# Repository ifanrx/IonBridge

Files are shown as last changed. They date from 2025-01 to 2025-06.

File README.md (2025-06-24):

# IonBridge

This repository contains the open-source power management module for the power adapter developed by ifanr / CANDYSIGN.

## 许可

请参阅 LICENSE 文件以了解更多详细信息。

我们欢迎非商业用途和小批量（单一型号总生产量小于等于一百台）使用。然而，对于大批量或盈利生产，需要获得商业许可。

请注意，虽然这是一个开源软件项目，但这并不意味着我们放弃了对该项目的版权。

## License
Please refer to the LICENSE file for more details.

We welcome non-commercial use and small batch runs. However, for larger batch or for-profit productions, a commercial license is required.

Please note that although this is an open-source software project, it does not mean we are relinquishing copyright to it.

## Contributing
The project is still in its early stages. We are currently sorting out copyright issues with our legal team to ensure we can legally acquire a perpetual, non-exclusive license for contributions while remaining in compliance with the relevant legal framework. 

As a result, we are unable to accept external contributions at this time. Stay tuned for updates! Once the issues are resolved, you will be required to sign a Contributor License Agreement (CLA) to authorize us to use your copyrighted work non-exclusively.

##  What's Missing
The proprietary implementation of power allocation is a patented feature and is not included in the open-source scope of this repository.

## Development Setup
To get started, you need to install the [ESP-IDF](https://docs.espressif.com/projects/esp-idf/en/latest/esp32/get-started/)

### Prerequisites
Install the required dependencies:

```bash
$ brew install cmake ninja dfu-util
# Install Python 3 if it's not already installed
$ brew install python3
```

### Getting ESP-IDF
Clone the ESP-IDF repository and set it up:

```bash
$ mkdir -p ~/esp
$ cd ~/esp
$ git clone --recursive https://github.com/espressif/esp-idf.git
$ cd esp-idf
$ git checkout v5.4
```

### Updating Submodules
Update the ESP-IDF submodules:

```bash
$ cd ~/esp/esp-idf
$ git submodule update --init --recursive
```

### Installing ESP-IDF Tools
Run the installation script to install the ESP-IDF tools:

```bash
$ ./install.sh all
```

### Setting Environment Variables
Set up the required environment variables:

```bash
$ . $HOME/esp/esp-idf/export.sh
```
Alternatively, you can add the following alias to your shell profile for convenience:

```bash
alias get_idf='. $HOME/esp/esp-idf/export.sh'
```

### Configure the ESP32 Target
Navigate to the project root directory and set the ESP32 target:

```bash
$ idf.py set-target esp32c3
```

Copy sdkconfig.develop or sdkconfig.fake to sdkconfig:

```bash
$ cp configs/sdkconfig.develop sdkconfig
```

### Build the Project
Build the project using the following command:

```bash
$ idf.py build
```

## HummingBoard
HummingBoard is a fully functional development board for the power adapter in this project, designed specifically for development and testing.

- **Comprehensive Features**: Provides a complete development environment for power conversion.
- **Schematic Support**: You can find detailed schematics and related documentation in [HummingBoard](/HummingBoard/).

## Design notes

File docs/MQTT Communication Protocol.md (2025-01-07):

# MQTT Communication Protocol

## Table of Contents

- [MQTT Communication Protocol](#mqtt-communication-protocol)
  - [Table of Contents](#table-of-contents)
  - [Overview](#overview)
  - [Design Architecture](#design-architecture)
    - [Device Information](#device-information)
    - [Message Structure](#message-structure)
      - [Status Byte](#status-byte)
      - [Example Response](#example-response)
    - [Command Handling](#command-handling)
  - [Core Components](#core-components)
    - [MQTT Message Schema](#mqtt-message-schema)
      - [Header](#header)
      - [Base Message Class](#base-message-class)
    - [Telemetry Commands](#telemetry-commands)
    - [Message Serialization](#message-serialization)
    - [Usage](#usage)
    - [Examples](#examples)
      - [Sending Device Boot Info](#sending-device-boot-info)
      - [Parsing Incoming Messages](#parsing-incoming-messages)

---

## Overview

We have developed an MQTT-based protocol that facilitates efficient and reliable communication between devices and cloud services. Key features of the protocol include:

- **Device Identification**: Utilizes a unique "PSN" (Product Serial Number) to accurately identify device-specific messages.
- **Optimized Message Serialization**: Implements binary serialization to significantly enhance communication efficiency and reduce payload size.
- **Flexible Structured Design**: Features a structured format for message headers and payloads, enabling seamless support for diverse telemetry data and control commands.

For a practical implementation, refer to [`mqtt_client.py`](../python/mqtt_client.py). This file contains the complete implementation of the mqtt communication protocol, and you can start your development by editing this Python file.

---

## Design Architecture

### Device Information

Each device is identified using a `PSN` (Product Serial Number), stored in the ESP32's `protected_data` partition under the key `serial_number`. This ensures unique identification for each device during communication.

---

### Message Structure

- **Header**: Includes service ID and payload length for efficient parsing.
- **Payload**: Varies based on command and data type.

#### Status Byte

- `0x00`: Success
- `0x01`: Failure
- Other bytes represent specific API-defined data.

#### Example Response

For the command `GET_POWER_SUPPLY_STATUS`:
- `0x00`: Indicates success.
- `0x1F`: Binary `11111` means 5 ports are active.

---

### Command Handling

The system supports unified handlers for both BLE and MQTT commands. This ensures consistent behavior across communication protocols.

---

## Core Components

### MQTT Message Schema

Header and payload structures are implemented in `mqtt_message.h` to define and serialize MQTT messages.

#### Header

```cpp
struct MQTTMessageHeader {
  uint16_t service;
  uint16_t message_id;
};
```

#### Base Message Class

```cpp
struct MQTTMessage {
  MQTTMessageHeader header;
  virtual ~MQTTMessage() = default;
  virtual std::vector<uint8_t> serialize() const;
};
```

### Telemetry Commands
Defined commands handle various telemetry and control tasks:

```cpp
enum TelemetryServiceCommand : uint16_t {
  STREAM_PORTS_STATUS = 0x0080,
  STREAM_DEVICE_STATUS = 0x0081,
  PING = 0x0100,
  DEVICE_BOOT_INFO = 0x0110,
  POWER_HISTORICAL_DATA = 0x0130,
  // Additional commands...
};
```

### Message Serialization
All message structures provide a serialize() method to convert their fields into a byte array for transmission.

Example: `StreamPortStatus`

```cpp
struct StreamPortStatus : MQTTMessage {
  uint8_t status;
  uint8_t port_status_map;
  PortStatusData ports[8];

  std::vector<uint8_t> serialize() const override {
    std::vector<uint8_t> payload = header.serialize();
    payload.emplace_back(status);
    payload.emplace_back(port_status_map);
    // Serialize each port's data
    for (const auto &port : ports) {
      const uint8_t *portData = reinterpret_cast<const uint8_t *>(&port);
      payload.insert(payload.end(), portData, portData + sizeof(PortStatusData));
    }
    return payload;
  }
};
```

### Usage
To integrate this framework into your project:

1. Include the mqtt_message.h header file in your project.
2. Define your specific telemetry or control commands.
3. Use the serialize() methods to prepare payloads for MQTT transmission.

### Examples
#### Sending Device Boot Info

```cpp
DeviceBootInfo bootInfo = { /* Initialize fields */ };
std::vector<uint8_t> payload = bootInfo.serialize();
// Send payload over MQTT
```

#### Parsing Incoming Messages

```cpp
void handleIncomingMessage(const std::vector<uint8_t>& payload) {
  // Deserialize based on header service ID
}
```

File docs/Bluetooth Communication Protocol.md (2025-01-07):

# Bluetooth Communication Protocol

## Table of Contents
- [Bluetooth Communication Protocol](#bluetooth-communication-protocol)
  - [Table of Contents](#table-of-contents)
  - [Overview](#overview)
  - [Protocol Design](#protocol-design)
    - [Message Structure](#message-structure)
    - [Flags](#flags)
  - [Key Functionalities](#key-functionalities)
    - [Message Size Encoding](#message-size-encoding)
    - [Checksum Validation](#checksum-validation)
  - [Communication Workflow](#communication-workflow)
  - [Example Workflow](#example-workflow)
    - [Device Status Request](#device-status-request)
  - [Code Snippets](#code-snippets)
    - [Message Processing](#message-processing)
    - [Exponential Backoff for Retransmissions](#exponential-backoff-for-retransmissions)

---

## Overview

We have designed a robust BLE communication protocol to enable fast, reliable, and secure interaction with devices. The protocol includes the following key features:

- **Data Encapsulation**: Ensures information integrity through modular and structured data transmission.
- **Optimized for Small MTU**: Tailored for efficient communication in environments with limited MTU sizes.
- **Sequence Control**: Ensures ordered and reliable data transmission using serialization mechanisms.
- **Built-in Information Verification**: Enhances communication security and reliability with integrated verification processes.

For a practical implementation, refer to [`ble_tester.py`](../python/ble_tester.py). This file contains the complete implementation of the Bluetooth communication protocol, and you can start your development by editing this Python file.

---

## Protocol Design

### Message Structure

Each message consists of a header and a payload:

```c
typedef struct { // 9 bytes
  uint8_t version;     // Protocol version 0x1 
  uint8_t id;          // Unique ID for each message
  int8_t service;      // Service ID (positive: send, negative: receive)
  uint8_t sequence;    // Sequence number for fragmentation
  uint8_t flags;       // Transmission control flags 
  ble_size_t size;     // Total size of the message payload
  uint8_t checksum;    // Checksum for integrity validation
} BLEHeader;

typedef struct {
  BLEHeader header;
  uint8_t payload[];    // Flexible array for payload data
} Message;
```

### Flags
The flags byte contains information for fragmentation and transmission control:

- Flags (Bits 0–2):

  * 0x0: NONE
  * 0x1: SYN (connection request)
  * 0x2: ACK (acknowledgment)
  * 0x3: FIN (termination request)
  * 0x4: RST (reset connection)
  * 0x5: SYN+ACK (connection acknowledgment)

- Fragmentation Flags (Bits 3–4):

  * 0x0: No fragment
  * 0x1: First fragment
  * 0x2: More fragments
  * 0x3: Last fragment

## Key Functionalities
### Message Size Encoding
ble_size_t is a 3-byte structure used to encode and decode the payload size efficiently:

```c
typedef struct {
    uint8_t bytes[3];
} ble_size_t;

// Convert `ble_size_t` to `uint32_t`
uint32_t get_ble_size_t(ble_size_t b) {
    uint32_t result = 0;
    result |= ((uint32_t)b.bytes[0]) << 16;
    result |= ((uint32_t)b.bytes[1]) << 8;
    result |= ((uint32_t)b.bytes[2]);
    return result;
}

// Convert `uint32_t` to `ble_size_t`
ble_size_t set_ble_size_t(uint32_t value) {
    ble_size_t b;
    b.bytes[0] = (value >> 16) & 0xFF;
    b.bytes[1] = (value >> 8) & 0xFF;
    b.bytes[2] = value & 0xFF;
    return b;
}
```
### Checksum Validation
The checksum field ensures message integrity:

```cpp
uint8_t calcChecksum(BLEHeader *header) {
    const uint8_t *begin = reinterpret_cast<const uint8_t *>(header);
    const uint8_t *end = begin + sizeof(BLEHeader) - 1; // Exclude checksum byte
    return std::accumulate(begin, end, static_cast<uint8_t>(0));
}

bool validateChecksum(BLEHeader *header) {
    uint8_t expected_checksum = header->checksum;
    header->checksum = 0;
    uint8_t calculated_checksum = calcChecksum(header);
    header->checksum = expected_checksum;
    return calculated_checksum == expected_checksum;
}
```

## Communication Workflow

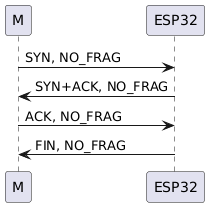
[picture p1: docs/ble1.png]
ble-1


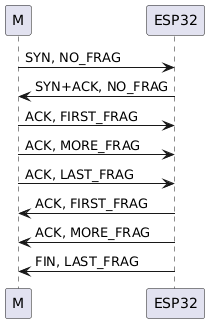
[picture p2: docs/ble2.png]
ble-2


1. Handshake (Connection Establishment)
Sender:
Sends a SYN packet with the requested service ID and optional payload.
Receiver:
Processes the payload and responds with a SYN+ACK packet.
This process reduces the usual three-way handshake to two steps for efficiency.

2. Data Exchange
For large data, use fragmentation (FRAG FLAGS):
First fragment: 0x1
More fragments: 0x2
Last fragment: 0x3
Receiver acknowledges (ACK) each received packet.
3. Connection Termination
Sender:
Sends a FIN packet, optionally with a final payload.
Receiver:
Processes the payload and responds with an ACK.
This simplified termination avoids the traditional four-step handshake, making the process faster.

## Example Workflow
### Device Status Request
1. Sender: Sends SYN requesting the device status.
2. Receiver: Responds with SYN+ACK, providing the current status.
3. Sender: Sends additional configuration requests.
4. Receiver: Responds with a FIN packet after completing the operation.
5. Sender: Acknowledges the FIN with an ACK.

## Code Snippets
### Message Processing
``` cpp
void process_message(Message &msg, IMessageHandler &handler) {
    ESP_LOGD(TAG, "Processing message with ID: %d", msg.getID());
    uint8_t flags = msg.getFlags() & 0x7;
    uint8_t frag_flags = (msg.getFlags() >> 3) & 0x3;

    switch (flags) {
        case SYN:
            handler.handle_syn(msg);
            break;
        case SYN_ACK:
            handler.handle_syn_ack(msg);
            break;
        case ACK:
            handler.handle_ack(msg);
            break;
        case FIN:
            handler.handle_fin(msg);
            break;
    }
}
```
### Exponential Backoff for Retransmissions
```cpp
const int backoff_intervals[] = {128, 256, 512, 1024, 2048, 4096};

void retransmit_message(Message &msg, int retry_count) {
    if (retry_count >= sizeof(backoff_intervals) / sizeof(backoff_intervals[0])) {
        ESP_LOGE(TAG, "Maximum retries reached");
        return;
    }
    int backoff = backoff_intervals[retry_count];
    ESP_LOGI(TAG, "Retransmitting message with backoff: %d ms", backoff);
    vTaskDelay(backoff / portTICK_PERIOD_MS);
    send_message(msg); // Assume send_message() handles actual transmission
}
```

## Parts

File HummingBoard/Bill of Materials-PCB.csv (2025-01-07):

Comment | Designator | Footprint | Quantity
ANT3216LL00R2400A | AE1 | ANT3216LL00R2400A | 1
CL05A106MQ5NUNC | C1_U_SW35660, C1_U_SW35661, C1_U_SW35662, C1_U_SW35663, C1_U_SW35664, C4_U_SW35660, C4_U_SW35661, C4_U_SW35662, C4_U_SW35663, C4_U_SW35664, C16_U_SW35660, C16_U_SW35661, C16_U_SW35662, C16_U_SW35663, C16_U_SW35664, C32, C40, C45, C48 | CAPC1005X06N | 19
CL05B104KB54PNC | C2_U_SW35660, C2_U_SW35661, C2_U_SW35662, C2_U_SW35663, C2_U_SW35664, C7_U_SW35660, C7_U_SW35661, C7_U_SW35662, C7_U_SW35663, C7_U_SW35664, C8_U_SW35660, C8_U_SW35661, C8_U_SW35662, C8_U_SW35663, C8_U_SW35664, C9_U_SW35660, C9_U_SW35661, C9_U_SW35662, C9_U_SW35663, C9_U_SW35664, C15_U_SW35660, C15_U_SW35661, C15_U_SW35662, C15_U_SW35663, C15_U_SW35664, C19, C24, C25, C30, C31, C35, C36, C41, C42, C43, C44, C46, C47, C49, C50, C51, C52, C53, C55, C56, C57, C58 | CAPC1005X06N | 47
GRM21BR61H106KE43L | C3_U_SW35660, C3_U_SW35661, C3_U_SW35662, C3_U_SW35663, C3_U_SW35664, C26 | CAPC2012X14N | 6
FS55X226K500EHG | C5_U_SW35660, C5_U_SW35661, C5_U_SW35662, C5_U_SW35663, C5_U_SW35664, C6_U_SW35660, C6_U_SW35661, C6_U_SW35662, C6_U_SW35663, C6_U_SW35664, C10_U_SW35660, C10_U_SW35661, C10_U_SW35662, C10_U_SW35663, C10_U_SW35664, C11_U_SW35660, C11_U_SW35661, C11_U_SW35662, C11_U_SW35663, C11_U_SW35664, C12_U_SW35660, C12_U_SW35661, C12_U_SW35662, C12_U_SW35663, C12_U_SW35664, C13_U_SW35660, C13_U_SW35661, C13_U_SW35662, C13_U_SW35663, C13_U_SW35664, C14_U_SW35660, C14_U_SW35661, C14_U_SW35662, C14_U_SW35663, C14_U_SW35664, C20, C21, C22, C23 | CAPC5750X31N | 39
0402B222K500NT | C17_U_SW35660, C17_U_SW35661, C17_U_SW35662, C17_U_SW35663, C17_U_SW35664 | CAPC1005X06N | 5
0402CG101J500NT | C18_U_SW35660, C18_U_SW35661, C18_U_SW35662, C18_U_SW35663, C18_U_SW35664 | CAPC1005X06N | 5
CL31A107MQHNNNE | C27 | CAPC3216X18N | 1
CL05B103KB5NNNC | C28, C37 | CAPC1005X06N | 2
0402B472K500NT | C29 | CAPC1005X06N | 1
CC0402BRNPO9BNR47 | C33 | CAPC1005X06N | 1
0402CGR75C500NT | C34 | CAPC1005X06N | 1
CL05A105KA5NQNC | C38, C39 | CAPC1005X06N | 2
CC0402KRX7R9BB332 | C54 | CAPC1005X06N | 1
SRV05-4-P-T7 | D1_U_SW35660, D1_U_SW35661, D1_U_SW35662, D1_U_SW35663, D1_U_SW35664 | SOT-23-6 | 5
P6SMB39A | D2 | SMB DO-214AA | 1
SS54C | D3 | SMC | 1
E6C0805URAC1UDA | D4 | DIOC2012X11N | 1
TYPE-C-31-M-12 | J1_U_SW35660, J1_U_SW35661, J1_U_SW35662, J1_U_SW35663, J1_U_SW35664, J3 | TYPE-C-31-M-12 | 6
XT60PW-M | J2 | XT60PW-M | 1
A1251WV-S-6P | J4 | A1251WV-S-6P | 1
B-3000N10P-0110 | J5 | B-3000N10P-0110 | 1
SER1360-103KLD | L1_U_SW35660, L1_U_SW35661, L1_U_SW35662, L1_U_SW35663, L1_U_SW35664, L2 | SER1360 | 6
MLG1005S1N8BT000 | L3, L5, L6 | INDC1005X06N | 3
VHF100505HQ1N5ST | L4 | INDC1005X06N | 1
RUH4040M2 | Q1_U_SW35660, Q1_U_SW35661, Q1_U_SW35662, Q1_U_SW35663, Q1_U_SW35664, Q2_U_SW35660, Q2_U_SW35661, Q2_U_SW35662, Q2_U_SW35663, Q2_U_SW35664, Q3_U_SW35660, Q3_U_SW35661, Q3_U_SW35662, Q3_U_SW35663, Q3_U_SW35664 | DNH0008A | 15
0402WGF1002TCE | R1_U_SW35660, R1_U_SW35661, R1_U_SW35662, R1_U_SW35663, R1_U_SW35664, R2_U_SW35660, R2_U_SW35661, R2_U_SW35662, R2_U_SW35663, R2_U_SW35664, R3_U_SW35660, R3_U_SW35661, R3_U_SW35662, R3_U_SW35663, R3_U_SW35664, R6_U_SW35660, R6_U_SW35661, R6_U_SW35662, R6_U_SW35663, R6_U_SW35664, R7_U_SW35660, R7_U_SW35661, R7_U_SW35662, R7_U_SW35663, R7_U_SW35664, R23, R24, R25, R27, R28, R29, R30, R31, R32, R34 | RESC1005X04N | 35
NCP15XH103F03RC | R4_U_SW35660, R4_U_SW35661, R4_U_SW35662, R4_U_SW35663, R4_U_SW35664 | RESC1005X04N | 5
RC0402FR-0710KL | R5_U_SW35660, R5_U_SW35661, R5_U_SW35662, R5_U_SW35663, R5_U_SW35664, R17 | RESC1005X04N | 6
RLM12FTCMR003 | R8_U_SW35660, R8_U_SW35661, R8_U_SW35662, R8_U_SW35663, R8_U_SW35664, R10 | RESC3116X06N | 6
0402WGF2002TCE | R9_U_SW35660, R9_U_SW35661, R9_U_SW35662, R9_U_SW35663, R9_U_SW35664, R19 | RESC1005X04N | 6
0603WAF500LT5E | R11, R12, R13, R14 | RESC1608X06N | 4
0402WGF3162TCE | R15 | RESC1005X04N | 1
0402WGF1003TCE | R16, R18 | RESC1005X04N | 2
0402WGF3300TCE | R20 | RESC1005X04N | 1
0402WGF5101TCE | R21, R22 | RESC1005X04N | 2
0402WGF1000TCE | R26 | RESC1005X04N | 1
0402WGF220JTCE | R33 | RESC1005X04N | 1
GT-TC029A-H020-L1A | S1 | GT-TC029A-H020-L1A | 1
MTP125-1101S1 | TP1_U_SW35660, TP1_U_SW35661, TP1_U_SW35662, TP1_U_SW35663, TP1_U_SW35664, TP2_U_SW35660, TP2_U_SW35661, TP2_U_SW35662, TP2_U_SW35663, TP2_U_SW35664, TP3_U_SW35660, TP3_U_SW35661, TP3_U_SW35662, TP3_U_SW35663, TP3_U_SW35664, TP4_U_SW35660, TP4_U_SW35661, TP4_U_SW35662, TP4_U_SW35663, TP4_U_SW35664, TP5_U_SW35660, TP5_U_SW35661, TP5_U_SW35662, TP5_U_SW35663, TP5_U_SW35664, TP6_U_SW35660, TP6_U_SW35661, TP6_U_SW35662, TP6_U_SW35663, TP6_U_SW35664, TP7_U_SW35660, TP7_U_SW35661, TP7_U_SW35662, TP7_U_SW35663, TP7_U_SW35664, TP8_U_SW35660, TP8_U_SW35661, TP8_U_SW35662, TP8_U_SW35663, TP8_U_SW35664, TP9_U_SW35660, TP9_U_SW35661, TP9_U_SW35662, TP9_U_SW35663, TP9_U_SW35664, TP10_U_SW35660, TP10_U_SW35661, TP10_U_SW35662, TP10_U_SW35663, TP10_U_SW35664, TP11_U_SW35660, TP11_U_SW35661, TP11_U_SW35662, TP11_U_SW35663, TP11_U_SW35664, TP12_U_SW35660, TP12_U_SW35661, TP12_U_SW35662, TP12_U_SW35663, TP12_U_SW35664, TP13, TP14, TP15 | MTP125-1101S1 | 63
SW3566H | U1_U_SW35660, U1_U_SW35661, U1_U_SW35662, U1_U_SW35663, U1_U_SW35664 | QFN-32 | 5
TP181A2-CR | U2 | 3PEAK SC70-6 SOT-363 | 1
TPS54240DGQR | U3 | DGQ0010D | 1
ESP32-C3 | U4 | ESPRESSIF-QFN32-5*5 | 1
W25Q64JVSSIQ | U5 | W25QXXXJVSIQ | 1
EF2M45LG48B | U6 | ANLOGIC_LQFP48 | 1
SiT2001BI-S1-33E-40.000000 | Y1 | SITIME_SIT2001_SOT23 | 1

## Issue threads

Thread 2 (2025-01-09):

功能请求：添加 Switch 底座识别功能，固定输出功率为 45W

chouch0u, 2025-01-09:
## 背景说明：
Nintendo Switch 在底座模式下对电源有特定的功率需求。通过自动识别 Switch 底座的连接，可以优化充电器输出，提供稳定的 45W 功率防止别的设备插入导致游戏中断。

## 具体需求：

### 识别机制：

充电器应通过 USB-PD 协议 PID VID 识别 Switch 底座。

### 固定输出功率：

当识别到 Switch 底座后，充电器自动切换到 45W（15V/3A）的固定输出模式。

### 兼容性保障：

在 Switch 底座识别失败或不兼容设备连接的情况下，充电器应回退到默认输出模式，避免不必要的误判。

### 预期收益：

提高充电器的设备适配能力，增加对 Switch 用户的吸引力。提供更稳定的输出功率，防止因功率分配导致的外接显示设备输出中断，提升用户体验。

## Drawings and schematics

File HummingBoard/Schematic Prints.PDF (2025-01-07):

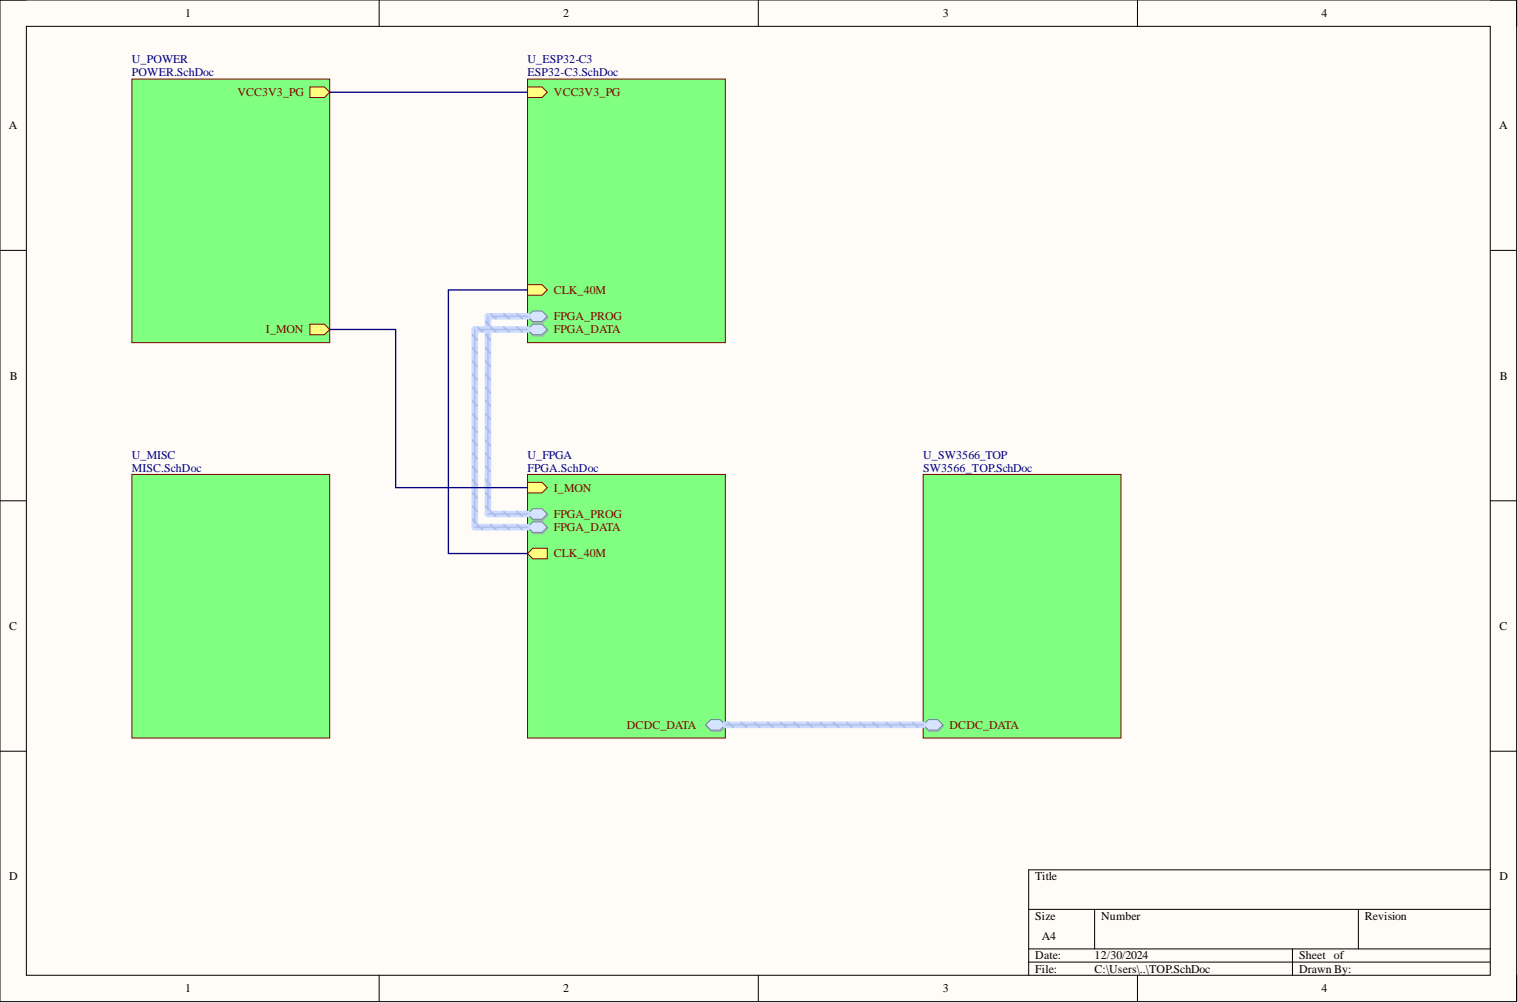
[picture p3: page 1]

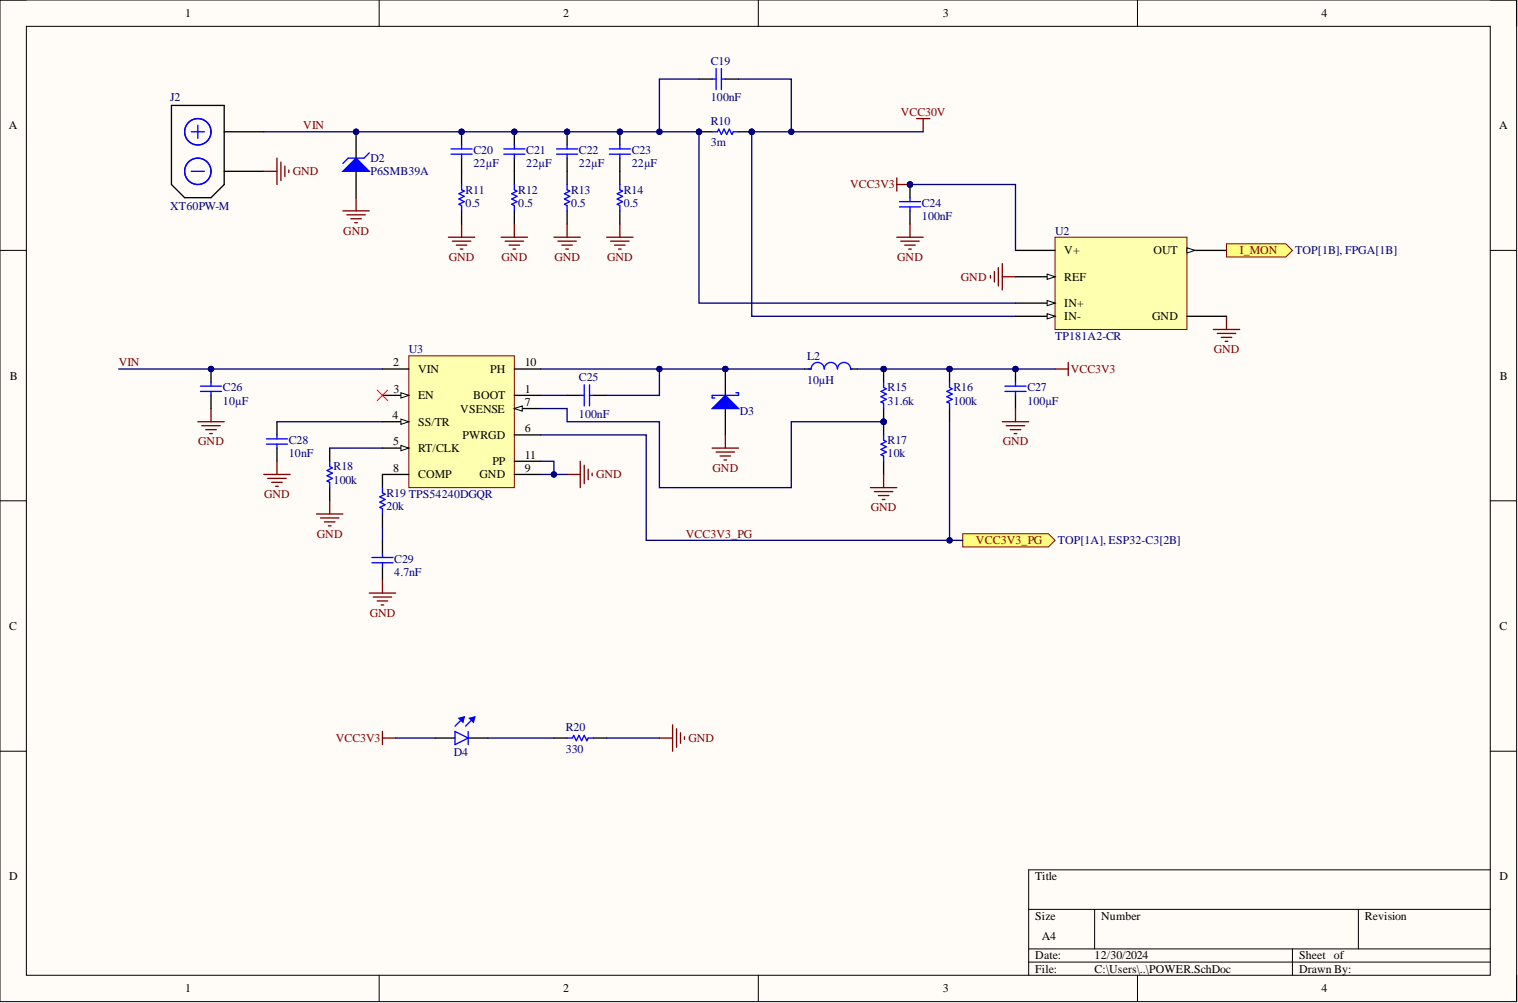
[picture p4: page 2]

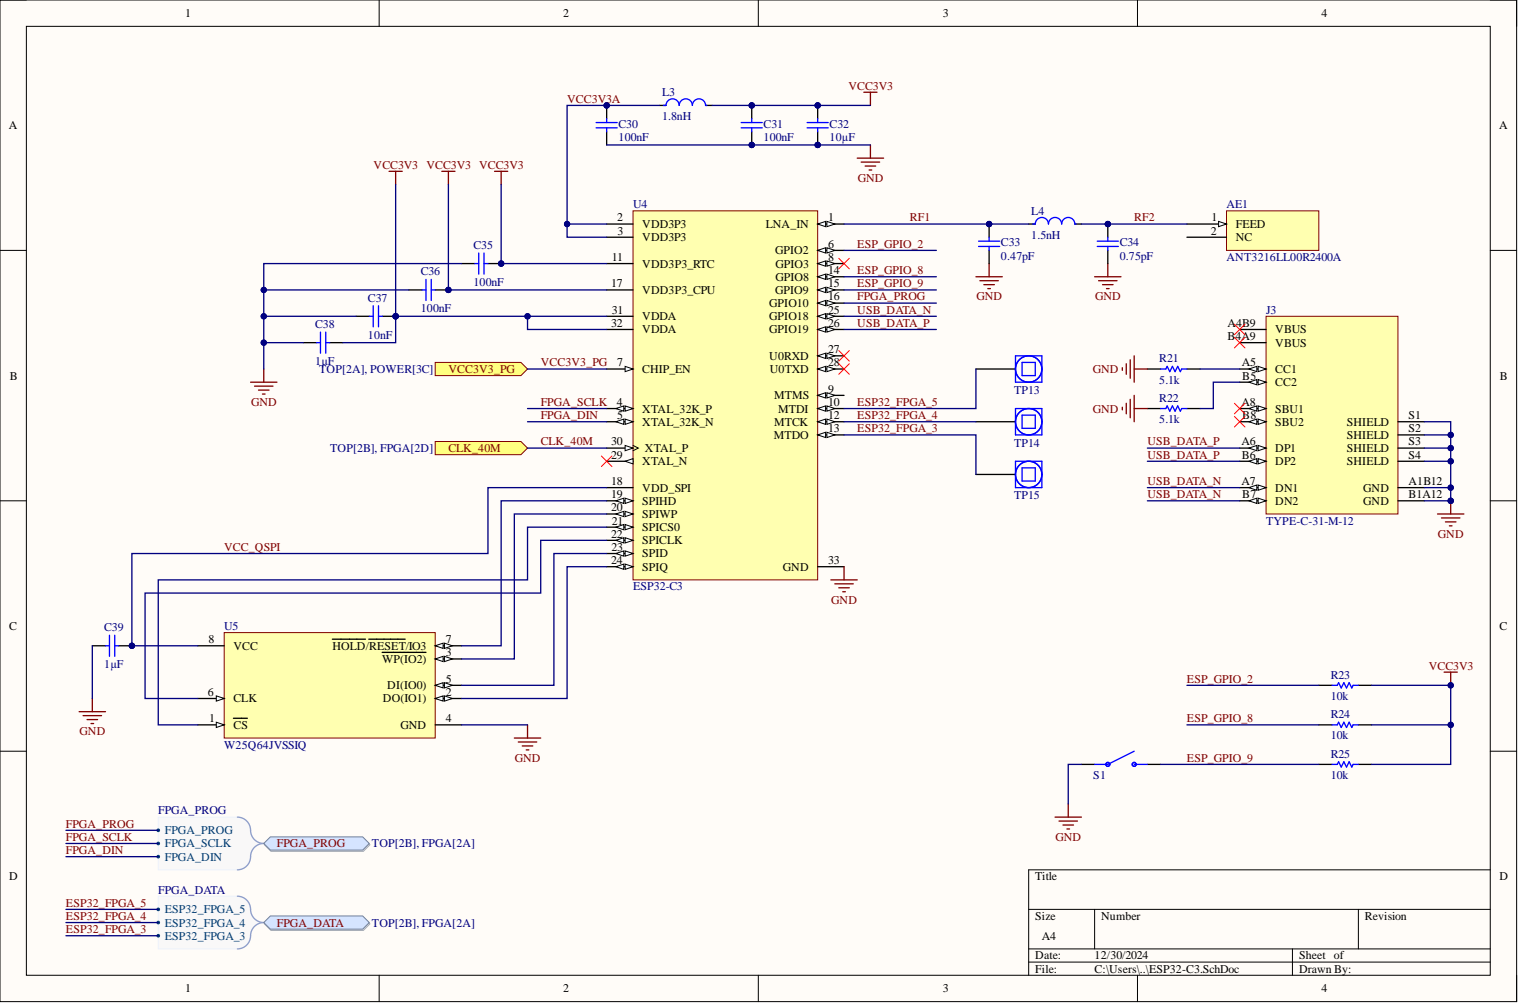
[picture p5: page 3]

SPIWP 20
SPICS0 21
SPICLK 22
SPID 23
SPIQ 24

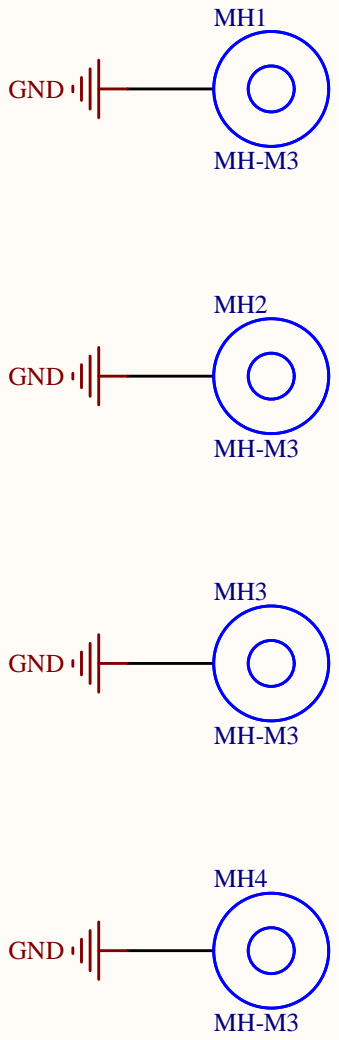
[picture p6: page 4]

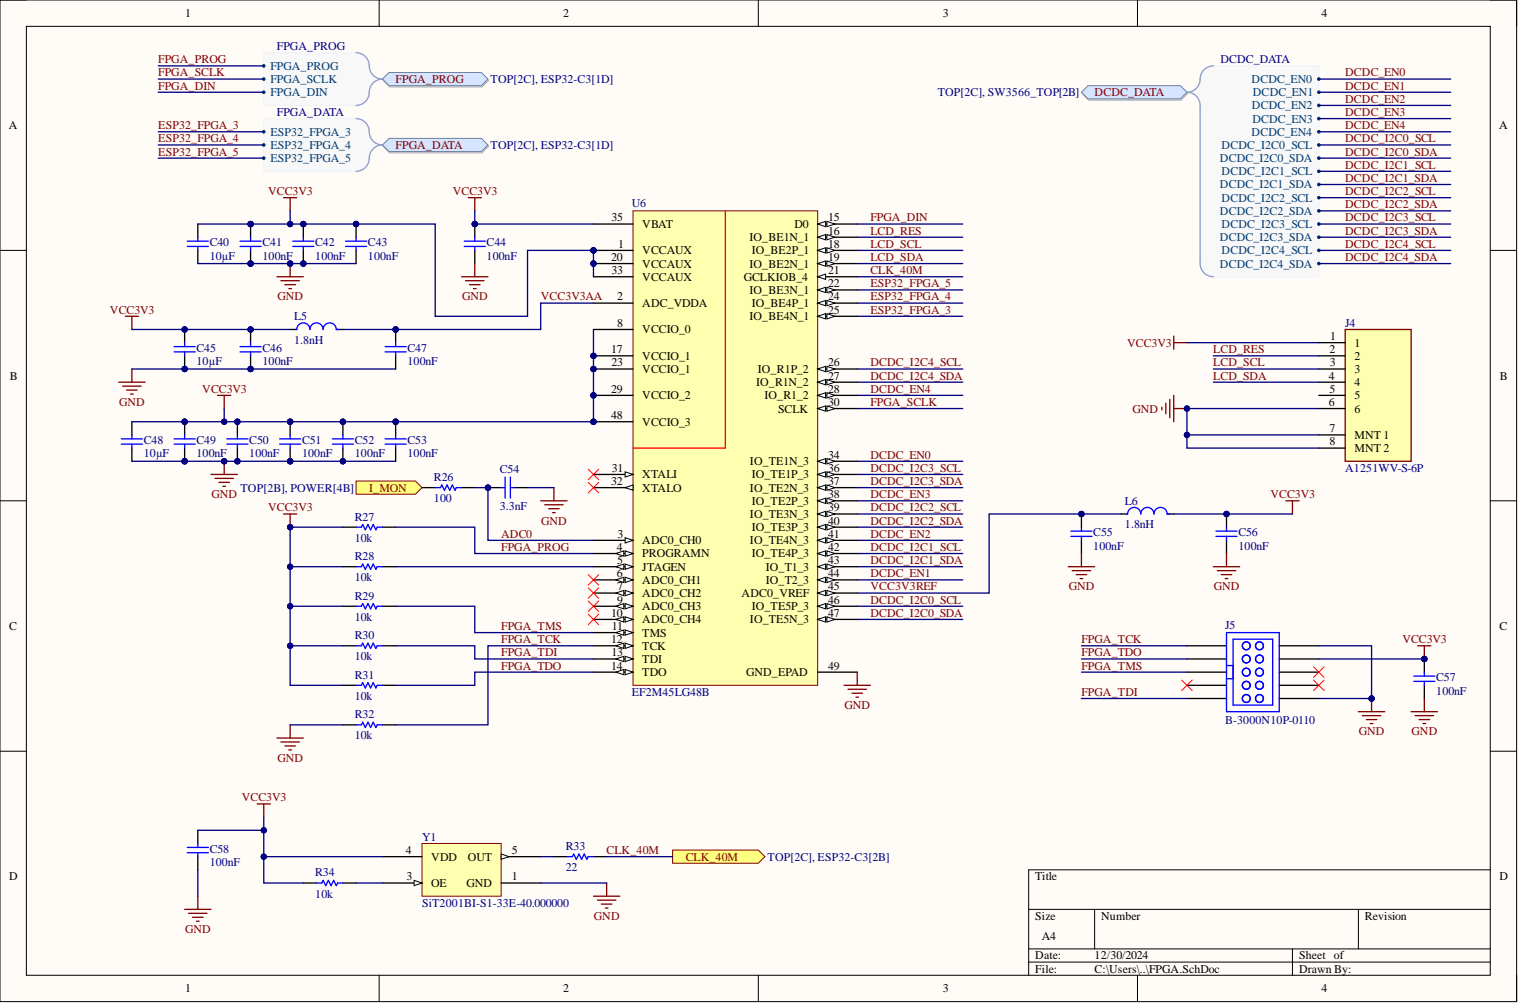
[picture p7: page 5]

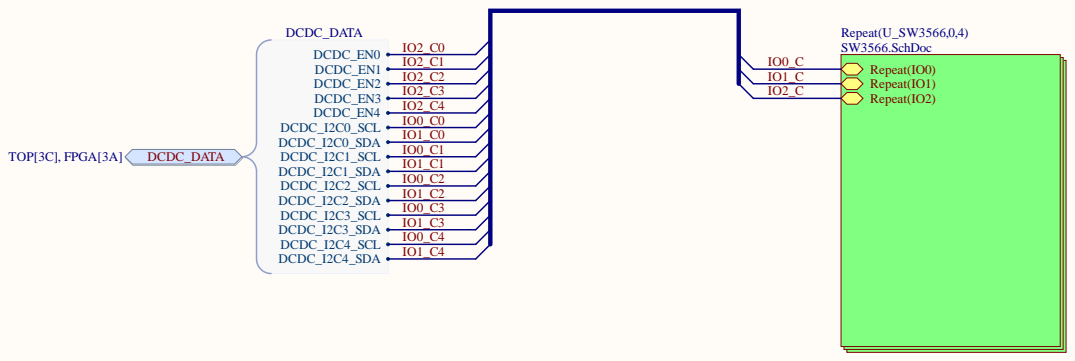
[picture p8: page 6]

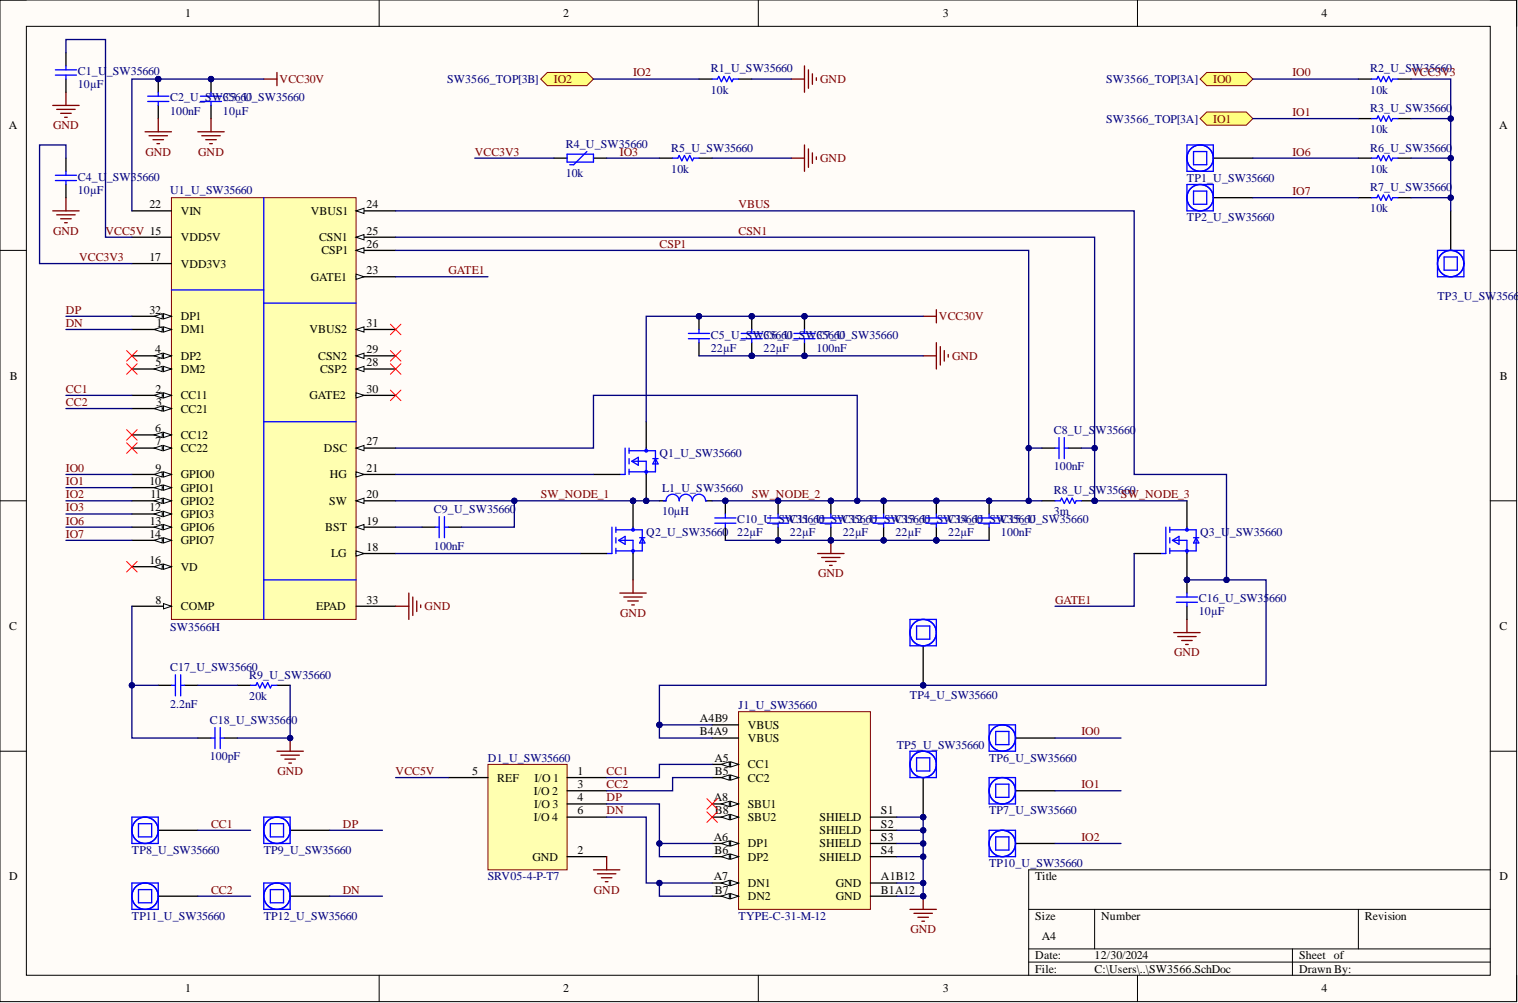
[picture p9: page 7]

VBUS B4A9

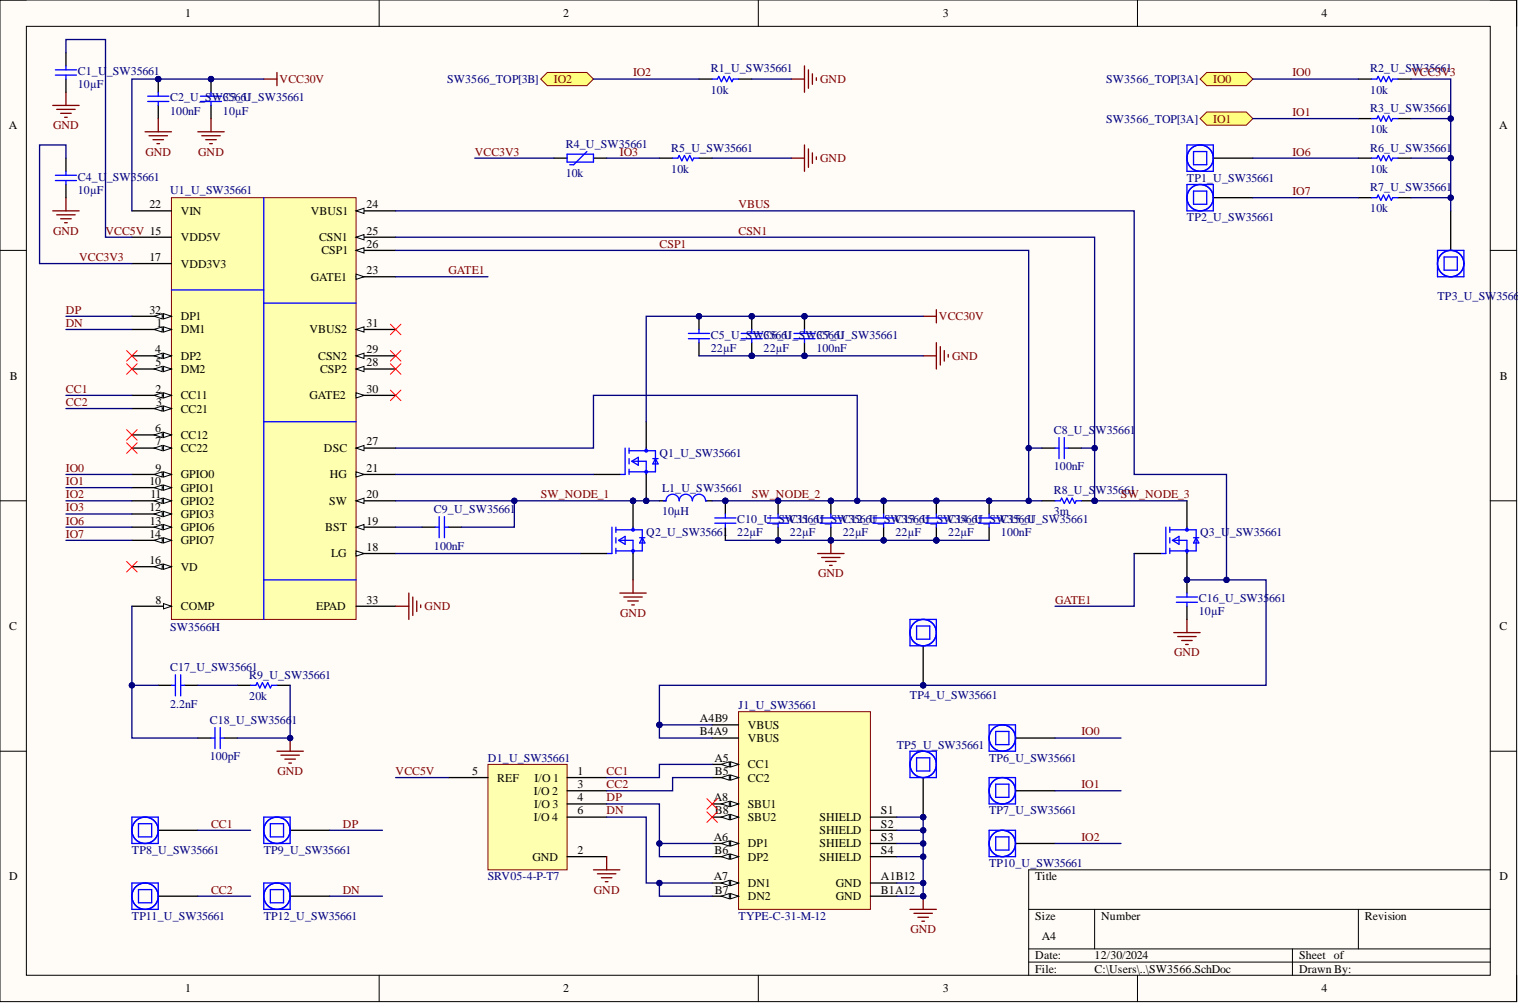
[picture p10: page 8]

VBUS B4A9

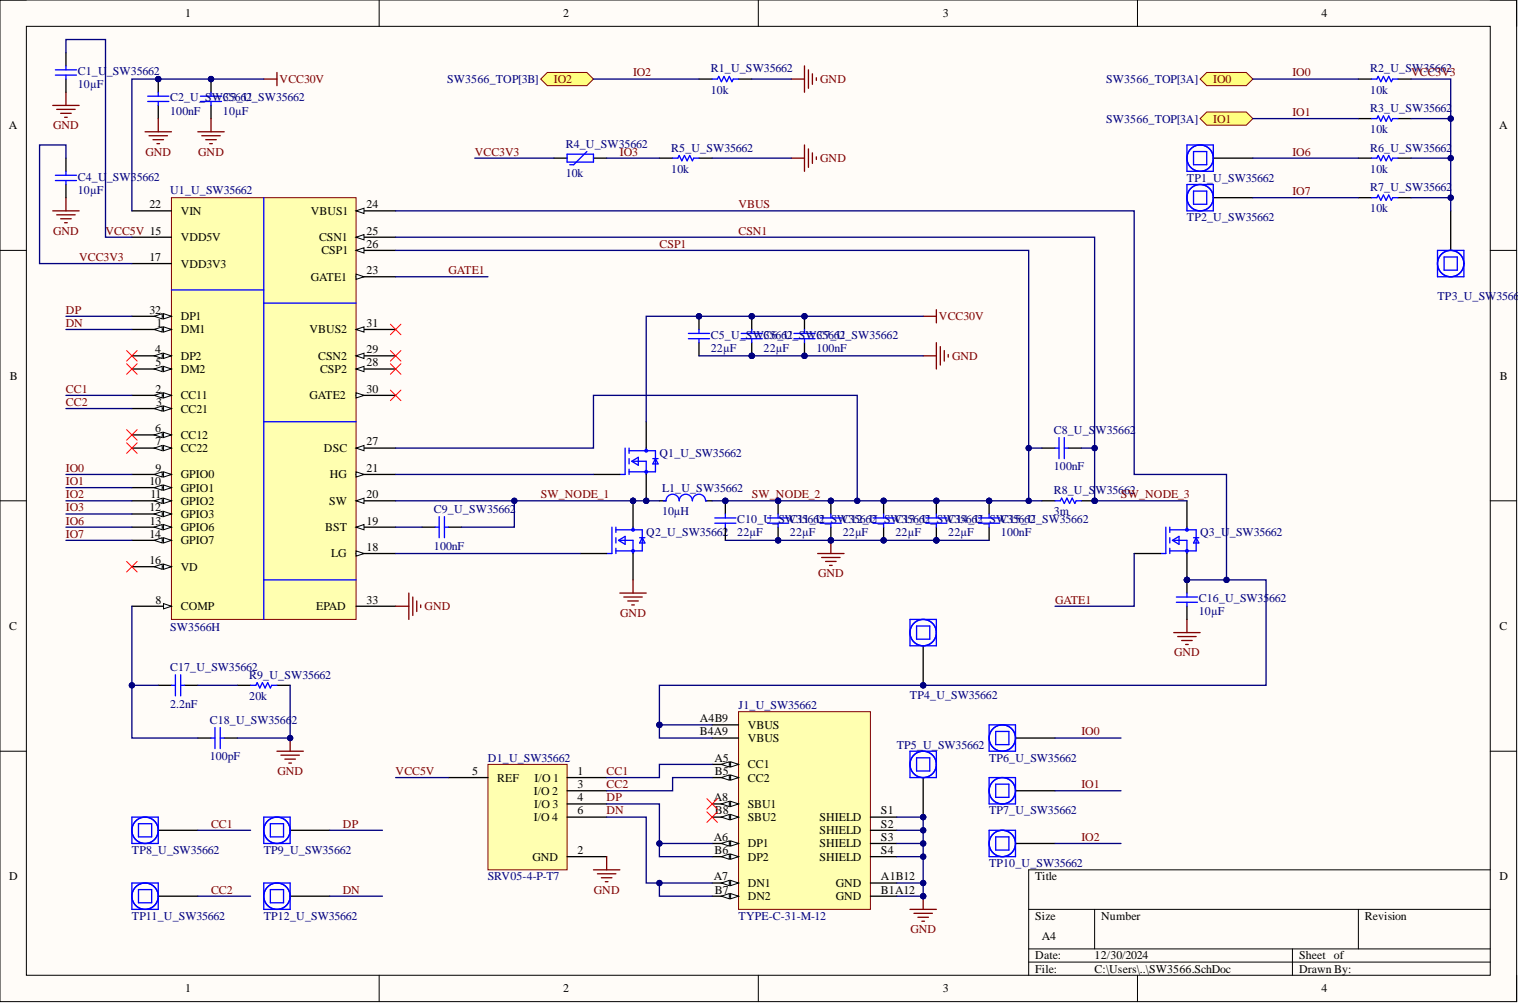
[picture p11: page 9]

VBUS B4A9

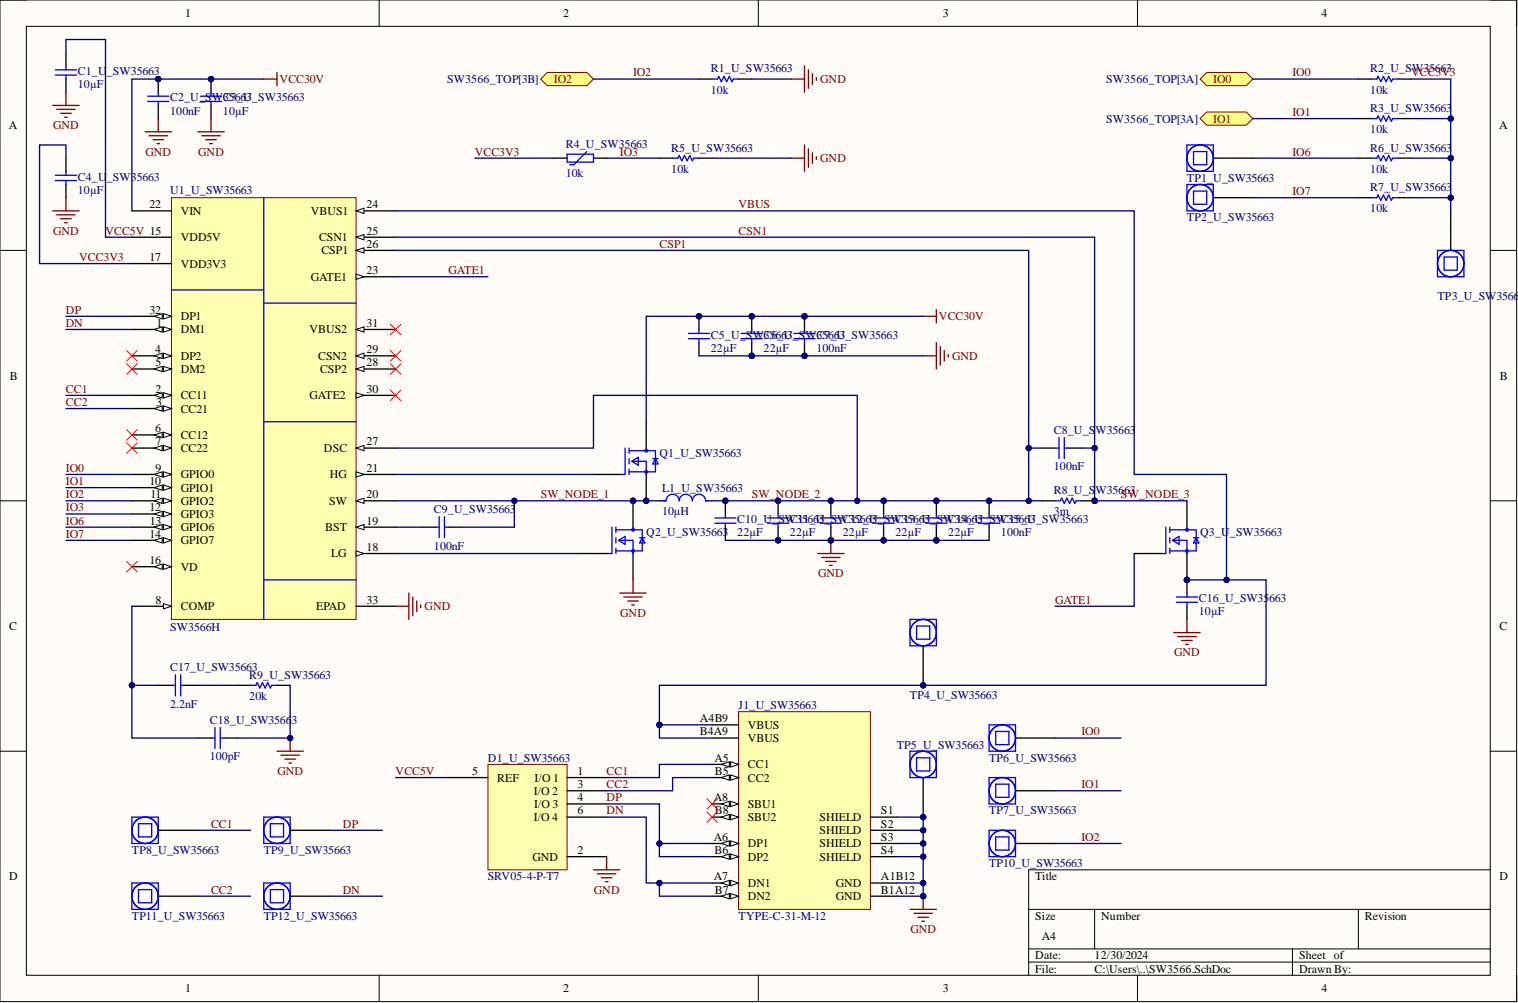
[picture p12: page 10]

VBUS B4A9

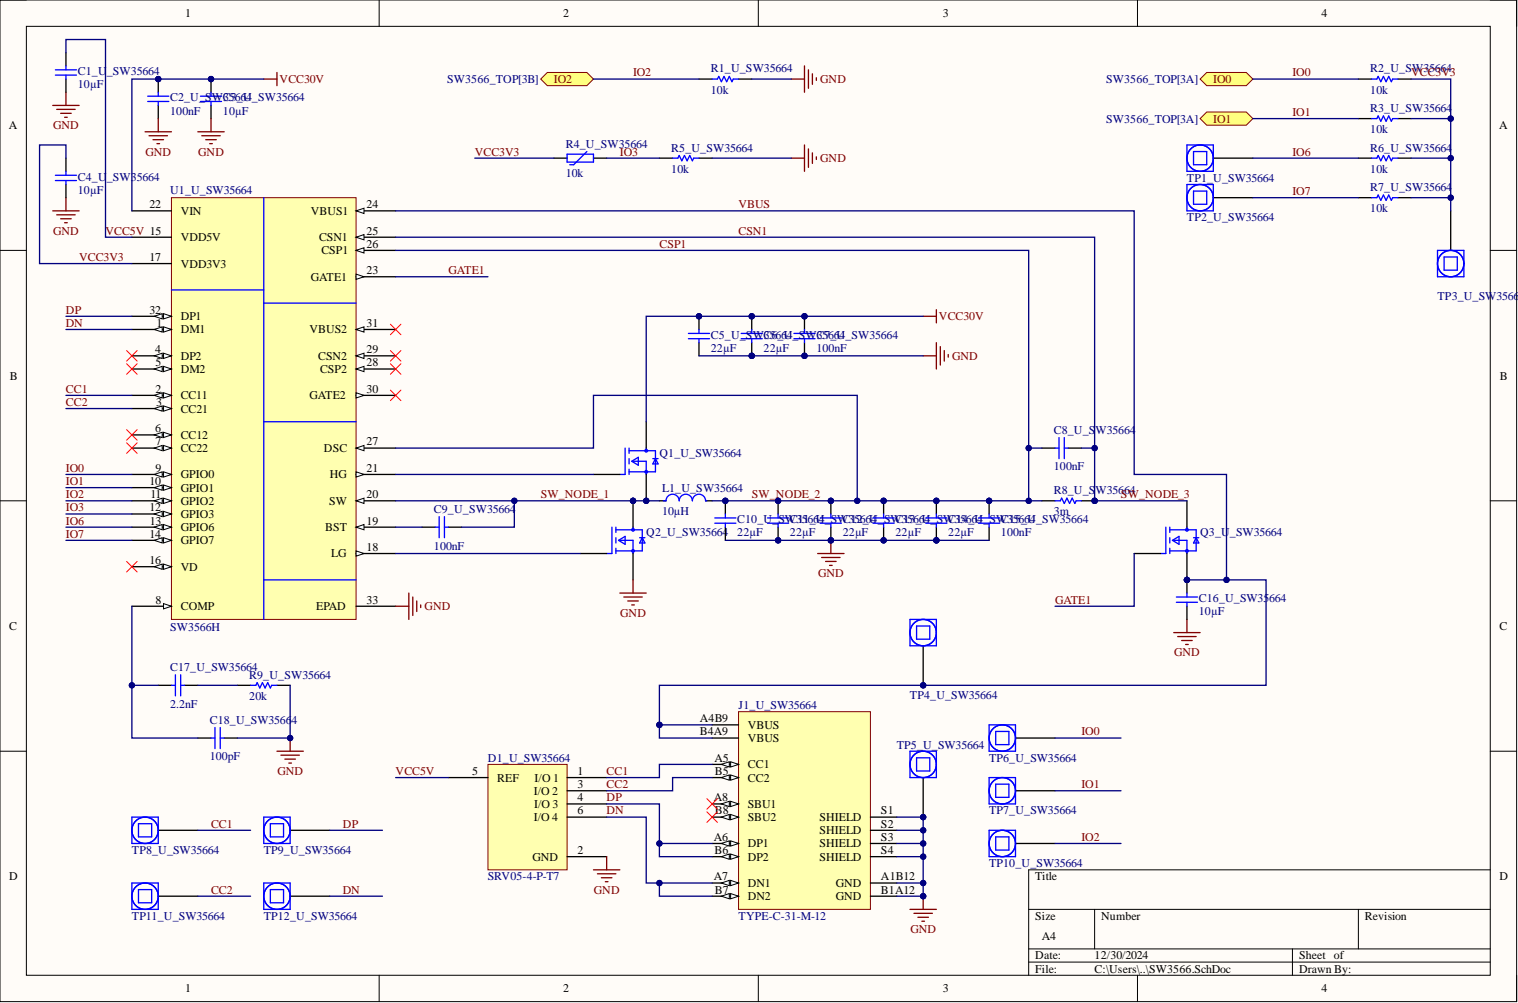
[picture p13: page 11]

VBUS B4A9

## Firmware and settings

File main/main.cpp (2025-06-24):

#include <inttypes.h>
#include <stdint.h>

#include <algorithm>
#include <cstddef>
#include <cstdint>
#include <cstring>
#include <set>
#include <string>

#include "FreeRTOSConfig.h"
#include "acdc.h"
#include "app.h"
#include "ble.h"
#include "controller.h"
#include "display_animation.h"
#include "display_manager.h"
#include "esp_check.h"
#include "esp_err.h"
#include "esp_heap_caps.h"
#include "esp_log.h"
#include "esp_log_level.h"
#include "esp_mac.h"
#include "esp_system.h"
#include "esp_task_wdt.h"
#include "esp_timer.h"
#include "freertos/FreeRTOS.h"  // IWYU pragma: keep
#include "freertos/task.h"      // IWYU pragma: keep
#include "handler.h"
#include "ionbridge.h"
#include "machine_info.h"
#include "mdns.h"
#include "mqtt_app.h"
#include "nvs.h"
#include "nvs_default.h"
#include "nvs_namespace.h"
#include "nvs_partition.h"
#include "port.h"
#include "port_manager.h"
#include "power_allocator.h"
#include "power_config.h"
#include "sdkconfig.h"
#include "storage.h"
#include "strategy.h"
#include "syslog.h"
#include "telemetry_task.h"
#include "utils.h"
#include "wifi.h"

#ifdef CONFIG_PM_ENABLE
#include "esp_pm.h"
#endif

#ifdef CONFIG_MCU_MODEL_SW3566
#include "fpga.h"
#endif

#if defined(CONFIG_MCU_MODEL_SW3566) || defined(CONFIG_MCU_MODEL_FAKE_SW3566)
#include "rpc.h"
#endif

#if defined(CONFIG_INTERFACE_TYPE_UART) && \
    !defined(CONFIG_MCU_MODEL_FAKE_SW3566)
#include "uart.h"
#endif

#ifdef CONFIG_ENABLE_FPGA_ADC_MONITOR
#define ENABLE_FPGA_ADC_MONITOR
#endif

#ifdef CONFIG_ENABLE_AUTO_STREAM_DATA
#define ENABLE_AUTO_STREAM_DATA
#endif

#define WATCHDOG_TIMEOUT CONFIG_WATCHDOG_TIMEOUT

#ifdef CONFIG_MCU_MODEL_SW3566
#define SW3566_FIRMWARE_NUMERIC_VERSION CONFIG_SW3566_FIRMWARE_NUMERIC_VERSION
#define FPGA_FIRMWARE_NUMERIC_VERSION CONFIG_FPGA_FIRMWARE_NUMERIC_VERSION

#if defined(CONFIG_SKIP_3566_UPGRADE) || defined(CONFIG_DEVICE_HUMMING_BOARD)
#define SKIP_3566_UPGRADE true
#else
#define SKIP_3566_UPGRADE false
#endif
#endif

#ifdef CONFIG_MCU_MODEL_SW3526_SW3566
#endif

#ifdef CONFIG_ENABLE_POWER_ALLOCATOR
#define ENABLE_POWER_ALLOCATOR
#endif

using namespace std;

extern "C" void app_main(void);

static const char *TAG = "IonBridge";

void feed_watchdog_task(void *arg);

#ifndef CONFIG_ENABLE_FACTORY_MODE
static MachineInfo &machine_info = MachineInfo::GetInstance();

static bool comm_interface_initialized = false;
#if !defined(CONFIG_MCU_MODEL_FAKE_SW3566)
static void comm_interface_init();
#endif
static bool chip_ready[NUM_PORTS];
static bool boot_chips();

static void start_mdns_service();

const int startup_task_max_run = 5;
const int startup_task_period_ms = 5 * 1000;
esp_timer_handle_t startup_task_timer;

#ifdef ENABLE_FPGA_ADC_MONITOR
void fpga_adc_monitor() {
  static uint8_t last_adc_value = 0;
  uint8_t adc_value = 0;
  esp_err_t ret = rpc::fpga::read_adc_value(&adc_value);
  if (ret == ESP_OK && adc_value != last_adc_value) {
    ESP_LOGI(TAG, "FPGA ADC value: 0x%02x", adc_value);
    last_adc_value = adc_value;
    return;
  }
  ESP_ERROR_COMPLAIN(ret, "rpc::fpga::read_adc_value");
}
#endif

void start_allocator() {
  init_power_config();
  AllocatorBuilder *builder = new AllocatorBuilder();
  builder->SetPortCount(NUM_PORTS);
  builder->SetTimerPeriod(100);    // collecting power data every 100ms
  builder->SetCooldownPeriod(10);  // sufficient time before reapplying
  builder->SetApplyPeriod(1000);   // applying power strategy every 1000ms
  builder->SetPortActiveState(chip_ready, NUM_PORTS);
  builder->SetStrategy<PowerSlowChargingStrategy>();
  PowerAllocator &allocator = builder->Build();
  delete builder;

  ESP_RETURN_VOID_ON_ERROR(allocator.Start(), TAG,
                           "Failed to start power allocator");

  bool enabled = true;
  PowerNVSGetOrDefault(&enabled, NVSKey::POWER_ALLOCATOR_ENABLED);
  if (!enabled) {
    ESP_LOGI(TAG, "Power allocation is disabled");
    allocator.DisablePowerAllocation();
  }

  DeviceController &controller = DeviceController::GetInstance();
  TelemetryTask &task = TelemetryTask::GetInstance();
  task.Start();

#ifndef CONFIG_DEVICE_HUMMING_BOARD
  PortManager &pm = PortManager::GetInstance();
  bool normally_booted =
      comm_interface_initialized && pm.GetActivePortCount() > 0;
  controller.set_normally_booted(normally_booted);
#else
  controller.set_normally_booted(comm_interface_initialized);
#endif
}

void set_port_configs() {
  NVSKey keys[] = {
      NVSKey::POWER_PORT0_CONFIG, NVSKey::POWER_PORT1_CONFIG,
      NVSKey::POWER_PORT2_CONFIG,
#if CONFIG_MCU_MODEL_SW3566
      NVSKey::POWER_PORT3_CONFIG, NVSKey::POWER_PORT4_CONFIG,
#endif
  };
  size_t keys_count = sizeof(keys) / sizeof(keys[0]);
  PortManager &pm = PortManager::GetInstance();
  for (Port &port : pm.GetAlivePorts()) {
    size_t i = port.Id();
    if (i >= keys_count) {
      continue;
    }

    PortConfig config = {};
    size_t size = sizeof(PortConfig);
    esp_err_t err =
        PowerNVSGet(reinterpret_cast<uint8_t *>(&config), &size, keys[i]);
    if (err == ESP_OK) {
      port.SetConfig(config);
      continue;
    }
    if (err == ESP_ERR_NVS_NOT_FOUND) {
      port.ApplyConfig();
      continue;
    }
    ESP_ERROR_COMPLAIN(err, "PowerNVSData::GetPortConfig: %d", i);
  }
}

#if defined(CONFIG_MCU_MODEL_SW3566) || defined(CONFIG_MCU_MODEL_FAKE_SW3566)
bool configure_fpga() {
#define DISPLAY_DEFAULT_MODE CONFIG_DISPLAY_MODE
#define DISPLAY_DEFAULT_INTENSITY CONFIG_DISPLAY_INTENSITY

  uint8_t displayMode = DISPLAY_DEFAULT_MODE;
  uint8_t displayIntensity = DISPLAY_DEFAULT_INTENSITY;
  uint8_t portPriorities[NUM_PORTS] = {0};
  uint8_t adc_threshold_low, adc_threshold_high, action_deadzone;
  size_t length;

  uint8_t adc_data[3];
  length = sizeof(adc_data);
  FPGANVSGetOrDefault(adc_data, &length, NVSKey::FPGA_CONFIG);
  adc_threshold_low = adc_data[0];
  adc_threshold_high = adc_data[1];
  action_deadzone = adc_data[2];
  ESP_LOGI(TAG, "ADC threshold: low=0x%x, high=0x%x, deadzone=0x%x",
           adc_threshold_low, adc_threshold_high, action_deadzone);
  // 设置拉断的 threshold
  ESP_RETURN_FALSE_ON_ERROR(
      rpc::fpga::set_adc_threshold(adc_threshold_low, adc_threshold_high),
      "rpc::fpga::set_adc_threshold: low=0x%x, high=0x%x", adc_threshold_low,
      adc_threshold_high);

  // 设置 action deadzone
  ESP_RETURN_FALSE_ON_ERROR(rpc::fpga::set_action_deadzone(action_deadzone),
                            "rpc::fpga::set_action_deadzone: deadzone=0x%x",
                            action_deadzone);

  // 加载端口优先级
  length = NUM_PORTS;
  PowerNVSGetOrDefault(portPriorities, &length, NVSKey::POWER_PORT_PRIORITY);
  for (uint8_t i = 0; i < length; i++) {
    ESP_RETURN_FALSE_ON_ERROR(rpc::fpga::set_mcu_priority(i, portPriorities[i]),
                              "set_mcu_priority: port %d=%d", i,
                              portPriorities[i]);
  }

#ifdef CONFIG_ENABLE_FPGA_POWER_CTRL
  bool enabled = true;
  FPGANVSGetOrDefault(&enabled, NVSKey::FPGA_POWER_CONTROL);
  if (enabled) {
    // 启用端口优先级功能
    ESP_RETURN_FALSE_ON_ERROR(rpc::fpga::toggle_power_control(),
                              "toggle_power_control");
  } else {
    ESP_LOGI(TAG, "FPGA power control disabled");
  }
#endif

  DisplayManager &display_manager = DisplayManager::GetInstance();
  ESP_RETURN_FALSE_ON_ERROR(display_manager.SetDisplayMode(displayMode),
                            "SetDisplayMode 0x%x", displayMode);

  ESP_RETURN_FALSE_ON_ERROR(
      display_manager.SetDisplayIntensity(displayIntensity),
      "SetDisplayIntensity 0x%x", displayIntensity);
  uint8_t displayFlip = 0x00;
  DisplayNVSGetOrDefault(&displayFlip, NVSKey::DISPLAY_FLIP);
  ESP_RETURN_FALSE_ON_ERROR(display_manager.SetDisplayFlipMode(displayFlip),
                            "SetDisplayFlipMode 0x%x", displayFlip);
  return true;
}
#endif

esp_err_t set_mac_address() {
  // Currently we use 6-bytes MAC address
  uint8_t mac[6];
  size_t length = sizeof(mac);

  ESP_RETURN_ON_ERROR(DeviceNVSGet(mac, &length, NVSKey::DEVICE_WIFI_MAC), TAG,
                      "get_device_wifi_mac");
  mac[0] &= 0xFE;  // Ensure Unicast bit is set
  ESP_RETURN_ON_ERROR(esp_iface_mac_addr_set(mac, ESP_MAC_WIFI_STA), TAG,
                      "esp_iface_mac_addr_set ESP_MAC_WIFI_STA");

  ESP_RETURN_ON_ERROR(DeviceNVSGet(mac, &length, NVSKey::DEVICE_BLUETOOTH_MAC),
                      TAG, "get_device_bluetooth_mac");
  ESP_RETURN_ON_ERROR(esp_iface_mac_addr_set(mac, ESP_MAC_BT), TAG,
                      "esp_iface_mac_addr_set ESP_MAC_BT");

  return ESP_OK;
}

void heap_caps_alloc_failed_hook(size_t requested_size, uint32_t caps,
                                 const char *function_name) {
  // Log warning message with allocation details
  ESP_LOGW(
      TAG,
      "Heap allocation failed - caller: %s, requested: %d bytes, caps: %" PRIu32
      ", free: %" PRIu32 " bytes",
      function_name, (int)requested_size, caps, esp_get_free_heap_size());
  // Only available in serial console
  heap_caps_print_heap_info(caps);

  MQTTClient *mqtt = MQTTClient::GetInstance();
  if (!mqtt) {
    // MQTT is unavailable, return
    return;
  }
  mqtt->SetLowMemoryMark();
  TelemetryTask::GetInstance().ReportOutOfMemory(caps);
}

#ifdef CONFIG_ENABLE_RFTEST
#warning "Ensure `sdkconfig.rftest` is used before compiling with ENABLE_RFTEST"
void cert_test() {
  uint32_t mode_args[6] = {};
  esp_err_t err = TestModeNVSData::GetAndEraseTestModeAArgs(mode_args);
  if (err != ESP_OK) {
    return;
  }
  ESP_LOGW(TAG, "Starting certification test");
  esp_phy_wifi_rate_t rate = static_cast<esp_phy_wifi_rate_t>(mode_args[1]);
  int8_t backoff = static_cast<int8_t>(mode_args[2]);
  ESP_LOGI(TAG,
           "Test mode A parameters - mode: %" PRIu32
           ", rate: %d, backoff: %d, "
           "param3: %" PRIu32 ", param4: %" PRIu32 ", param5: %" PRIu32,
           mode_args[0], rate, (int)backoff, mode_args[3], mode_args[4],
           mode_args[5]);
  esp_wifi_power_domain_on();
  esp_phy_rftest_config(1);
  esp_phy_rftest_init();
  esp_phy_tx_contin_en(true);
  esp_phy_test_start_stop(3);
  esp_phy_wifi_tx(mode_args[0], rate, backoff, mode_args[3], mode_args[4],
                  mode_args[5]);
  while (true) {
    vTaskDelay(pdMS_TO_TICKS(1000));
  }
}
#endif

static void report_startup_status_task(void *) {
  static int run_count = 0;
  run_count++;
  PowerAllocator &allocator = PowerAllocator::GetInstance();
  PortManager &pm = PortManager::GetInstance();
  if (!comm_interface_initialized) {
#if CONFIG_MCU_MODEL_SW3566
    ESP_LOGW(TAG, "STARTUP_FAILED_FPGA");
#elif !defined(CONFIG_MCU_MODEL_FAKE_SW3566)
    ESP_LOGW(TAG, "STARTUP_FAILED_I2C");
#endif
  } else if (!allocator.IsConfigured()) {
#ifndef CONFIG_MCU_MODEL_FAKE_SW3566
    ESP_LOGW(TAG, "STARTUP_FAILED_ALLOCATOR");
#endif
  } else {
    uint8_t active_ports = pm.GetActivePortCount();
    if (active_ports == NUM_PORTS) {
      ESP_LOGW(TAG, "STARTUP_SUCCESS");
    } else {
#if CONFIG_MCU_MODEL_SW3566
      for (int i = 0; i < NUM_PORTS; i++) {
        if (!chip_ready[i]) {
          ESP_LOGW(TAG, "SW3566_%d_BOOT_FAILED", i);
        }
      }
      ESP_LOGW(TAG, "STARTUP_FAILED_SW3566: active_ports=%d", active_ports);
#endif
    }
  }

  if (run_count >= startup_task_max_run) {
    ESP_ERROR_COMPLAIN(esp_timer_stop(startup_task_timer),
                       "Failed to stop startup status timer");
    ESP_ERROR_COMPLAIN(esp_timer_delete(startup_task_timer),
                       "Failed to delete startup status timer");
  }
}

static void report_startup_status() {
  const esp_timer_create_args_t startup_task_timer_args = {
      .callback = report_startup_status_task,
      .arg = NULL,
      .dispatch_method = ESP_TIMER_TASK,
      .name = "report_startup_status",
      .skip_unhandled_events = true,
  };
  ESP_ERROR_COMPLAIN(
      esp_timer_create(&startup_task_timer_args, &startup_task_timer),
      "Failed to create startup status timer");
  report_startup_status_task(NULL);  // Run once immediately without waiting
  ESP_ERROR_COMPLAIN(esp_timer_start_periodic(startup_task_timer,
                                              startup_task_period_ms * 1e3),
                     "Failed to start periodic startup status timer");
}

#if CONFIG_MCU_MODEL_FAKE_SW3566
static void update_fake_mode() {
  char model[8];
  size_t length = sizeof(model);
  DeviceNVSGet(model, &length, NVSKey::DEVICE_MODEL);
  if (strncmp(model, "fake", 8) == 0) {
    return;
  }
  char fake_model[] = "fake";
  ESP_LOGW(TAG, "Setting model to '%s'", fake_model);
  NVSNamespace::SSet(fake_model, NVSKey::DEVICE_MODEL, strlen(fake_model),
                     PROTECTED_DATA_NVS_PARTITION, DEVICE_DATA_NVS_NAMESPACE);
}
#endif

static void start_boot_animation() {
  ESP_LOGI(TAG, "Creating boot animation");
  DisplayManager &display_manager = DisplayManager::GetInstance();
  display_manager.SetAnimation(AnimationType::BOOT_APP, false);
}

static void handle_system_reboot() {
  ESP_LOGW(TAG, "should_reboot requested, rebooting");
  for (Port &port : PortManager::GetInstance()) {
    port.Shutdown();
  }
  esp_restart();
}

static void register_syslog_handler() {
#ifdef CONFIG_ENABLE_GLOBAL_LOGGING_COLLECTOR
  SyslogClient &syslog = SyslogClient::GetInstance();
  ESP_ERROR_COMPLAIN(syslog.Initialize(), "Failed to initialize syslog");
  syslog.Register(wifi_is_connected());
#endif
}

void app_main() {
#ifdef CONFIG_PM_ENABLE
  static const esp_pm_config_t pm_config = {
      .max_freq_mhz = 160,
      .min_freq_mhz = 80,
  };
#endif

  esp_err_t ret __attribute__((unused));
#if !CONFIG_ESP_TASK_WDT_INIT
  // If the TWDT was not initialized automatically on startup,
  // manually initialize it now
  esp_task_wdt_config_t twdt_config = {
      .timeout_ms = WATCHDOG_TIMEOUT,
      .idle_core_mask = (1 << portNUM_PROCESSORS) - 1,  // Bitmask of all cores
      .trigger_panic = true,
  };
  ESP_ERROR_COMPLAIN(esp_task_wdt_init(&twdt_config), "esp_task_wdt_init");
  ESP_LOGI(TAG, "TWDT initialized");
  xTaskCreate(feed_watchdog_task, "wdg", 1.5 * 1024, NULL,
              CONFIG_WATCHDOG_TASK_PRIORITY, nullptr);
#endif  // CONFIG_ESP_TASK_WDT_INIT

  esp_log_level_set("wifi", ESP_LOG_WARN);
  esp_log_level_set("mqtt_client", ESP_LOG_WARN);
  esp_log_level_set("mqtt5_client", ESP_LOG_WARN);
  heap_caps_register_failed_alloc_callback(heap_caps_alloc_failed_hook);

  reset_acdc();

  // Initialize NVS partitions
  ESP_GOTO_ON_ERROR(NVSPartition::Init(), AFTER_NVS_INIT, TAG,
                    "Failed to initialize NVS partition");
  set_mac_address();
  machine_info.LoadFromStorage();
  machine_info.PrintInfo();

AFTER_NVS_INIT:
  ESP_ERROR_COMPLAIN(Storage::Init(), "Failed to initialize storage");

  DisplayManager &display_manager = DisplayManager::GetInstance();
  ESP_GOTO_ON_ERROR(display_manager.Init(), AFTER_DISPLAY_INIT, TAG,
                    "Failed to initialize display manager");
  display_manager.StartTask();

AFTER_DISPLAY_INIT:

#ifdef CONFIG_ENABLE_RFTEST
  cert_test();
#endif

#ifdef CONFIG_PM_ENABLE
  ESP_ERROR_COMPLAIN(esp_pm_configure(&pm_config),
                     "Failed to configure power management");
#endif

  ESP_ERROR_COMPLAIN(start_ble_adv_task(),
                     "Failed to start BLE advertising task");

#ifdef CONFIG_ENABLE_GLOBAL_LOGGING_COLLECTOR
  SyslogClient::GetInstance().Register();
#endif

  PortManager::GetInstance().StartTask();
#if CONFIG_MCU_MODEL_FAKE_SW3566
  update_fake_mode();
  ESP_LOGI(TAG, "Using fake SW3566 chip - all data is simulated");
  memset(chip_ready, true, sizeof(chip_ready));
  comm_interface_initialized = true;
#else
  comm_interface_init();
#endif  // CONFIG_MCU_MODEL_FAKE_SW3566

  DeviceController &controller = DeviceController::GetInstance();
  if (!comm_interface_initialized) {
    // Rollback due to communication interface initialization failure
    ESP_LOGW(
        TAG,
        "Communication interface initialization failed - performing rollback");
    controller.try_rollback();
  } else {
    start_boot_animation();
  }

  /* Start Wi-Fi task after initializing communication interface.
   * This ensures we can display animations during Wi-Fi connection.
   * If communication interface initialization fails, the system will roll back.
   * Otherwise, the Wi-Fi task will run without animation support.
   */
  if (wifi_initialize() == ESP_OK) {
    start_mdns_service();
    WiFiController::StartTask();
    if (!MQTTClient::Initialize()) {
      ESP_LOGE(TAG,
               "Failed to initialize MQTT client - remote control "
               "functionality will be unavailable");
    }
  } else {
    ESP_LOGE(TAG, "Failed to initialize Wi-Fi - system will be unavailable");
  }

  App &app = App::GetInstance();
  Handler::RegisterAllServices(app);

  // Boot chips concurrently with Wi-Fi task to save time
  if (comm_interface_initialized) {
    // Boot chips
    if (!boot_chips()) {
      ESP_LOGE(TAG, "All chips failed to boot - performing rollback");
      controller.try_rollback();
    } else {
      controller.try_confirm();
    }

    // If rollback occurs, system will reboot
#ifdef ENABLE_POWER_ALLOCATOR
    start_allocator();
#endif  // ENABLE_POWER_ALLOCATOR
    set_port_configs();
  }

  report_startup_status();

#ifdef ENABLE_FPGA_ADC_MONITOR
  int64_t last_time = esp_timer_get_time(), first_time = last_time, now = 0;
#endif

  while (true) {
    DELAY_MS(1 * 1000);

    register_syslog_handler();

    if (controller.should_reboot()) {
      handle_system_reboot();
    }

#ifdef ENABLE_AUTO_STREAM_DATA
    TelemetryTask::GetInstance().SubscribeTelemetryStream();
#endif

#ifdef ENABLE_FPGA_ADC_MONITOR
    now = esp_timer_get_time();
    if (now <= first_time + 30 * 1000 * 1000) {
      continue;
    }
    if (now <= last_time + 5 * 1000 * 1000) {
      continue;
    }
    last_time = now;
    if (!controller.is_upgrading()) {
      fpga_adc_monitor();
    }
#endif  // ENABLE_FPGA_ADC_MONITOR
  }

#if !CONFIG_ESP_TASK_WDT_INIT
  // If we manually initialized the TWDT, deinitialize it now
  ESP_ERROR_CHECK_WITHOUT_ABORT(esp_task_wdt_deinit());
  ESP_LOGI(TAG, "TWDT deinitialized");
#endif  // !CONFIG_ESP_TASK_WDT_INIT
}

#if !defined(CONFIG_MCU_MODEL_FAKE_SW3566)
void comm_interface_init() {
  comm_interface_initialized = false;
#if CONFIG_INTERFACE_TYPE_UART
  ESP_LOGI(TAG, "Initializing communication interface: UART");
  ESP_RETURN_VOID_ON_ERROR(uart_init(), TAG, "Failed to initialize UART");
  fpga_init();
  uint8_t value;
  ESP_RETURN_VOID_ON_ERROR(rpc::fpga::read_adc_value(&value), TAG,
                           "FPGA is not operational");
  comm_interface_initialized = configure_fpga();
#endif
}
#endif

/*
 * Boot all MCU chips, return true if any chip was successfully booted
 */
bool boot_chips() {
  memset(chip_ready,
#ifdef CONFIG_ALL_PORTS_ENABLED
         true,
#else
         false,
#endif
         sizeof(chip_ready));

#ifndef CONFIG_ALL_PORTS_ENABLED
#ifdef CONFIG_PORT_0_ENABLED
  chip_ready[0] = true;
#endif
#ifdef CONFIG_PORT_1_ENABLED
  chip_ready[1] = true;
#endif
#ifdef CONFIG_PORT_2_ENABLED
  chip_ready[2] = true;
#endif
#ifdef CONFIG_PORT_3_ENABLED
  chip_ready[3] = true;
#endif
#ifdef CONFIG_PORT_4_ENABLED
  chip_ready[4] = true;
#endif
#endif

#if CONFIG_MCU_MODEL_SW3566
  for (uint8_t i = 0; i < NUM_PORTS; i++) {
    esp_err_t err = rpc::fpga::toggle_mcu_gpio(i);
    chip_ready[i] = err == ESP_OK;
    if (chip_ready[i]) {
      ESP_LOGI(TAG, "Chip %d GPIO toggled - will reboot shortly", i);
    } else {
      ESP_LOGE(TAG, "Failed to toggle GPIO for chip %d", i);
    }
  }
  ESP_LOGI(TAG, "Waiting for chips to return to bootloader");
  DELAY_MS(3000);  // 3-second delay for chips to stabilize
  ESP_LOGI(TAG, "Booting all chips");
  rpc::mcu::boot_all(chip_ready, NUM_PORTS, SKIP_3566_UPGRADE);
#endif
  return std::any_of(chip_ready, chip_ready + NUM_PORTS,
                     [](bool b) { return b; });
}
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
void app_main() {
  ESP_LOGI(TAG, "Entering factory mode");
  esp_task_wdt_config_t twdt_config = {
      .timeout_ms = WATCHDOG_TIMEOUT,
      .idle_core_mask = (1 << portNUM_PROCESSORS) - 1,  // Bitmask of all cores
      .trigger_panic = true,
  };
  esp_err_t ret = esp_task_wdt_init(&twdt_config);
  ESP_ERROR_CHECK(ret);
  ESP_LOGI(TAG, "TWDT initialized");
  xTaskCreate(feed_watchdog_task, "wdg", 1.5 * 1024, NULL,
              CONFIG_WATCHDOG_TASK_PRIORITY, nullptr);

#ifdef CONFIG_INTERFACE_TYPE_UART
  ESP_RETURN_VOID_ON_ERROR(Storage::Init(), TAG, "Storage::Init failed");
  ESP_RETURN_VOID_ON_ERROR(uart_init(), TAG, "uart_init() failed");
  fpga_init();
  uint8_t value;
  ESP_RETURN_VOID_ON_ERROR(rpc::fpga::read_adc_value(&value), TAG,
                           "FPGA is not operational");

#if CONFIG_MCU_MODEL_SW3566
  for (uint8_t i = 0; i < NUM_PORTS; i++) {
    esp_err_t err = rpc::fpga::toggle_mcu_gpio(i);
    if (err == ESP_OK) {
      ESP_LOGI(TAG, "Chip %d GPIO toggled, will reboot shortly.", i);
    } else {
      ESP_LOGE(TAG, "Failed to toggle GPIO for chip %d", i);
    }
  }
  ESP_LOGI(TAG, "Waiting for chips to return to bootloader");
  DELAY_MS(3000);  // 3-second delay for chips to settle

#endif
#endif

  while (true) {
    DELAY_MS(1000);
  }
}
#endif

void feed_watchdog_task(void *arg) {
  ESP_ERROR_CHECK(esp_task_wdt_add(nullptr));     // Subscribe this task to TWDT
  ESP_ERROR_CHECK(esp_task_wdt_status(nullptr));  // Check if it is subscribed
  ESP_LOGI(TAG, "TWDT is subscribed");
  while (true) {
    if (esp_get_free_heap_size() < 6 * 1024) {
      // If the free heap size is less than 6KB, restart the system to free up
      // memory
      ESP_LOGW(TAG,
               "Free heap size is below 6KB: %" PRIu32 " - restarting system",
               esp_get_free_heap_size());
      esp_restart();
    }
    esp_task_wdt_reset();  // Feed watchdog timer
    DELAY_MS(50);
  }
  vTaskDelete(NULL);
}

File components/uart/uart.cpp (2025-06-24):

#include "driver/uart.h"

#include <endian.h>
#include <inttypes.h>
#include <stdint.h>
#include <stdio.h>
#include <stdlib.h>
#include <string.h>
#include <strings.h>
#include <sys/param.h>

#include <algorithm>

#include "driver/uart.h"
#include "esp_check.h"
#include "esp_err.h"
#include "esp_log.h"
#include "freertos/idf_additions.h"
#include "freertos/portmacro.h"
#include "freertos/projdefs.h"
#include "hal/uart_types.h"
#include "ionbridge.h"
#include "port_manager.h"
#include "sdkconfig.h"
#include "soc/clk_tree_defs.h"
#include "task_map.h"
#include "uart.h"
#include "utils.h"

#ifdef CONFIG_FPGA_AS_UART_SWITCH
#define FPGA_AS_UART_SWITCH
#define UART_BAUD_RATE 921600
#else
#define UART_BAUD_RATE (CONFIG_UART_BAUD_RATE)
#endif

#define UART_PORT_NUM (uart_port_t)(CONFIG_UART_PORT_NUM)
#define UART_RXD (CONFIG_UART_RXD)
#define UART_TXD (CONFIG_UART_TXD)
#define UART_QUEUE_SIZE (CONFIG_UART_RX_QUEUE_SIZE)
#define UART_ENQUEUE_TIMEOUT \
  pdMS_TO_TICKS(CONFIG_UART_RX_QUEUE_ENQUEUE_TIMEOUT_MS)
#define UART_TX_TARGETS (CONFIG_UART_TX_TARGETS)
#define UART_EVENT_TASK_PRIORITY (CONFIG_UART_EVENT_TASK_PRIORITY)
#define UART_NOTIFY_INDEX (1)

#ifdef CONFIG_UART_TX_BUFFER_ENABLE
#define ENABLE_UART_TX_BUFFER
#endif
#ifdef CONFIG_UART_COMM_DEBUG
#define UART_COMM_DEBUG
#endif
#ifdef CONFIG_UART_COMM_DEBUG_DATA
#define UART_COMM_DEBUG_DATA
#endif
#ifdef CONFIG_UART_STATE_DEBUG
#define UART_STATE_DEBUG
#endif

#define HIGH_BYTE_U16(value) ((uint8_t)((value) >> 8))
#define LOW_BYTE_U16(value) ((uint8_t)((value) & 0xFF))
#define UART_MESSAGE_PREAMBLE 0x5A5A
#define UART_MESSAGE_PREAMBLE_H HIGH_BYTE_U16(UART_MESSAGE_PREAMBLE)
#define UART_MESSAGE_PREAMBLE_L LOW_BYTE_U16(UART_MESSAGE_PREAMBLE)
#define UART_MESSAGE_POSTAMBLE 0xA5A5
#define UART_MESSAGE_POSTAMBLE_H HIGH_BYTE_U16(UART_MESSAGE_POSTAMBLE)
#define UART_MESSAGE_POSTAMBLE_L LOW_BYTE_U16(UART_MESSAGE_POSTAMBLE)
#define UART_MESSAGE_PROHIBIT_COMMAND 0x00FF

#define UART_MESSAGE_SEND_ATTEMPTS (CONFIG_UART_MESSAGE_SEND_ATTEMPTS)
#define UART_CRITICAL_MESSAGE_SEND_ATTEMPTS \
  (CONFIG_UART_CRITICAL_MESSAGE_SEND_ATTEMPTS)
#define UART_MESSAGE_RECV_ATTEMPTS (CONFIG_UART_MESSAGE_RECV_ATTEMPTS)
#define UART_MESSAGE_RECV_TIMEOUT_MS (CONFIG_UART_MESSAGE_RECV_TIMEOUT_MS)
#define UART_CRITICAL_MESSAGE_RECV_TIMEOUT_MS \
  (CONFIG_UART_CRITICAL_MESSAGE_RECV_TIMEOUT_MS)

// Address(1 byte): SRC ADDR (4 bits) | DST ADDR (4 bits)
#define UART_MESSAGE_ADDR_MASK 0x0F
#define UART_MESSAGE_ADDR(addr) (uint8_t)(addr & UART_MESSAGE_ADDR_MASK)
#define UART_MESSAGE_ADDR_COMBINE(src_addr, dst_addr)      \
  ((uint8_t)((uint8_t)(UART_MESSAGE_ADDR(src_addr) << 4) | \
             UART_MESSAGE_ADDR(dst_addr)))
#define UART_MESSAGE_SRC_ADDR(addr) UART_MESSAGE_ADDR(addr >> 0x4)
#define UART_MESSAGE_DST_ADDR(addr) UART_MESSAGE_ADDR(addr)
#define UART_MESSAGE_TO_ESP32(addr) (UART_MESSAGE_DST_ADDR(addr) == ESP32_ADDR)
#define UART_MESSAGE_TO_FPGA(addr) (UART_MESSAGE_DST_ADDR(addr) == FPGA_ADDR)
#define UART_MESSAGE_FROM_FPGA(addr) (UART_MESSAGE_SRC_ADDR(addr) == FPGA_ADDR)
#define UART_MESSAGE_BROADCAST(addr) (UART_MESSAGE_DST_ADDR(addr) == BCAST_ADDR)
#define UART_RESET_DATA "\x5A\xA5\x5A\xA5"

#define UART_BUF_SIZE (UART_MESSAGE_MAX_SZ * 4)
#define UART_TX_TARGET_IS_FPGA(addr) \
  (UART_MESSAGE_TO_FPGA(addr) || UART_MESSAGE_FROM_FPGA(addr))
#define UART_TX_TARGET_INDEX(addr)                                             \
  ((UART_TX_TARGET_IS_FPGA(addr)                                               \
        ? (UART_TX_TARGETS - 1)                                                \
        : (UART_MESSAGE_ADDR(addr) < UART_TX_TARGETS ? UART_MESSAGE_ADDR(addr) \
                                                     : UART_TX_TARGETS - 1)))
#define EXPECTED_RESPONSE(message, command) (message.command == command)

#define LOG_UART_MESSAGE(tag, msg_ptr, level)                             \
  do {                                                                    \
    uint8_t data[UART_MESSAGE_MAX_SZ];                                    \
    size_t offset = 0;                                                    \
    uint16_t temp = htobe16((msg_ptr)->preamble);                         \
    memcpy(data + offset, &temp, sizeof(temp));                           \
    offset += sizeof(temp);                                               \
    memcpy(data + offset, &(msg_ptr)->addr, sizeof((msg_ptr)->addr));     \
    offset += sizeof((msg_ptr)->addr);                                    \
    temp = htobe16((msg_ptr)->command);                                   \
    memcpy(data + offset, &temp, sizeof(temp));                           \
    offset += sizeof(temp);                                               \
    memcpy(data + offset, &(msg_ptr)->length, sizeof((msg_ptr)->length)); \
    offset += sizeof((msg_ptr)->length);                                  \
    memcpy(data + offset, (msg_ptr)->payload, (msg_ptr)->length);         \
    offset += (msg_ptr)->length;                                          \
    temp = htobe16((msg_ptr)->checksum);                                  \
    memcpy(data + offset, &temp, sizeof(temp));                           \
    offset += sizeof(temp);                                               \
    temp = htobe16((msg_ptr)->postamble);                                 \
    memcpy(data + offset, &temp, sizeof(temp));                           \
    offset += sizeof(temp);                                               \
    ESP_LOG_BUFFER_HEX_LEVEL(tag, data, offset, level);                   \
  } while (0)

static const char *TAG = "UART";

typedef struct {
  SemaphoreHandle_t sem;
  uint16_t command;
#ifndef FPGA_AS_UART_SWITCH
  uint8_t mcu_addr;
#endif
} UartRxSemaphore;
typedef struct {
  SemaphoreHandle_t sem;
  uint16_t command;
  uint8_t mcu_addr;
} UartTxSemaphore;

static bool uart_initialized = false;
#ifdef FPGA_AS_UART_SWITCH
static UartRxSemaphore uart_rx_sems[UART_TX_TARGETS];
#else
static UartRxSemaphore uart_rx_sem;
#endif
static UartTxSemaphore uart_tx_sem;
static TaskMap uart_task_map{};
static uart_metrics_t uart_metrics{};

static QueueHandle_t uart_queue;
static QueueHandle_t uart_rx_queues[UART_TX_TARGETS];

// Forward declarations of helper functions
static void log_invalid_uart_message(const uart_message_t &message);
static void reset_uart_state();
static void dispatch_uart_message(const uart_message_t &message);
static esp_err_t encode_uart_message(const uart_message_t *message,
                                     uint8_t *data);

static uart_state_t UART_STATE = {
    .state = GET_PREAMBLE0,
    .received_bytes = 0,
};
static uart_message_t UART_MESSAGE = {};
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

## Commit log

2025-06-24 feat: Bug fixes and performance improvements
    [esp32c3-4mdevboard.csv, partitions.csv, release-partitions.csv]
2025-08-08 chore: Add CNC Plate.step file for HummingBoard.
    [CNC Plate.step]
2025-11-14 fix: resolve formatting and temperature handling issues
    - Fix parameter formatting corruption in GetDeviceModel function declaration
    - Allow all services to run at high temperatures by disabling temperature checks
2025-11-14 fix(handler): correct function parameter formatting in device_handler.h
    - Fixed indentation and removed stray characters in GetDeviceModel function
